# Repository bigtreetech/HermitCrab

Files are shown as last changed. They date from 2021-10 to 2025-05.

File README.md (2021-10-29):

# HermitCrab
* [CanbusKlipper](https://github.com/bigtreetech/HermitCrab/tree/master/CanbusKlipper) contains information about the HermitCrab
 Canbus version
 
 * [Hero Me Gen5 hotend assembly part cooling system](https://www.thingiverse.com/thing:4460970) contains the part cooling system STL files for HermitCrab

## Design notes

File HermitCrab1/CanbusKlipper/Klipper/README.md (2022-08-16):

# How to use Klipper on HermitCrab Canbus version

## Pinout
### HermitCrab Canbus pinout
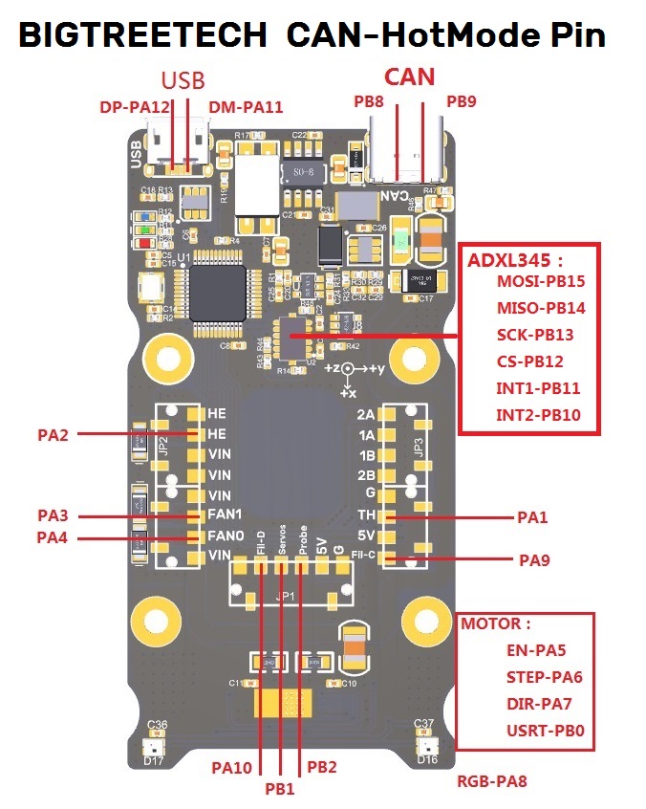
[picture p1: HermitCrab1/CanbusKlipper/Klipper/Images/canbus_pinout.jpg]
<br/>

## Wiring diagram
### Raspberry pi communicates with the hotend board via USB
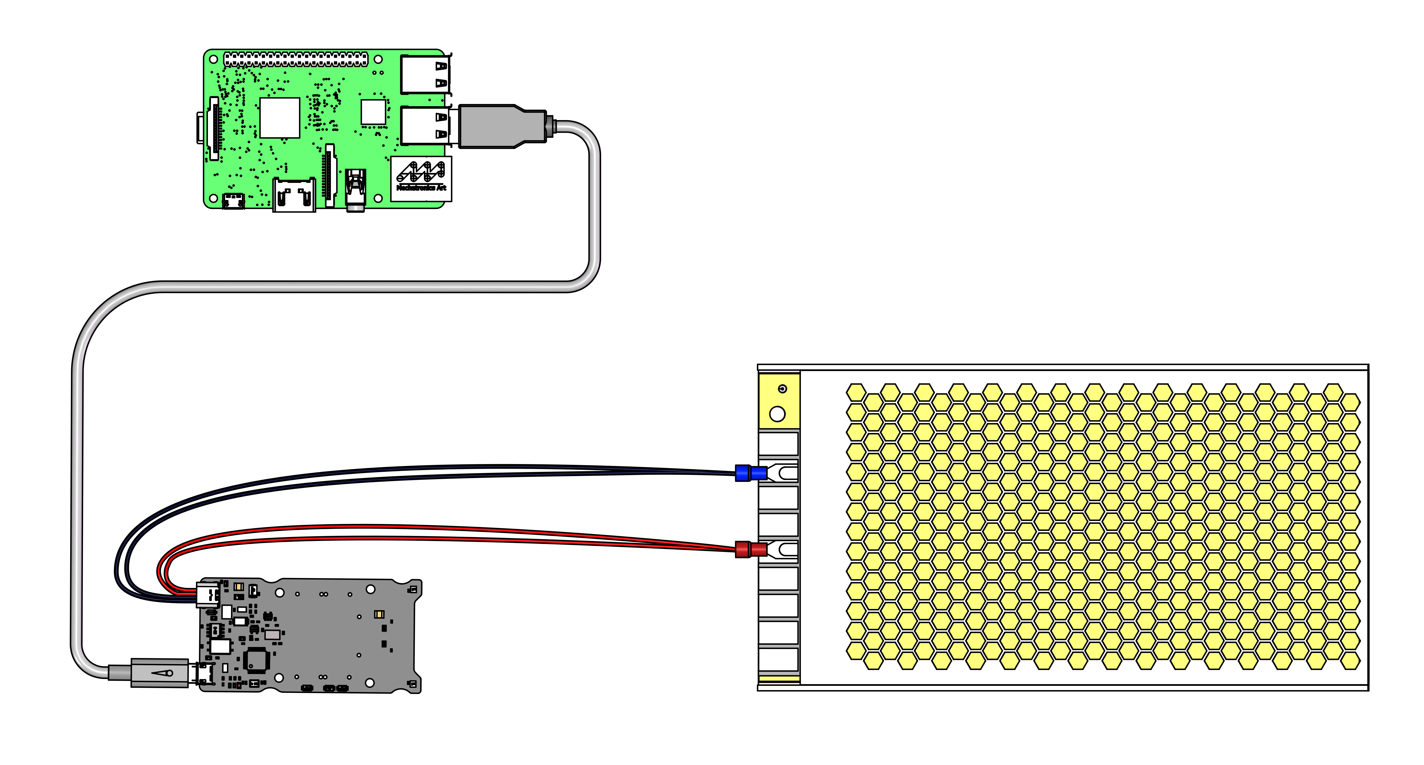
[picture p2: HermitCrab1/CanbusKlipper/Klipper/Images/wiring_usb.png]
<br/>

### Raspberry pi communicates with the hotend board via Canbus
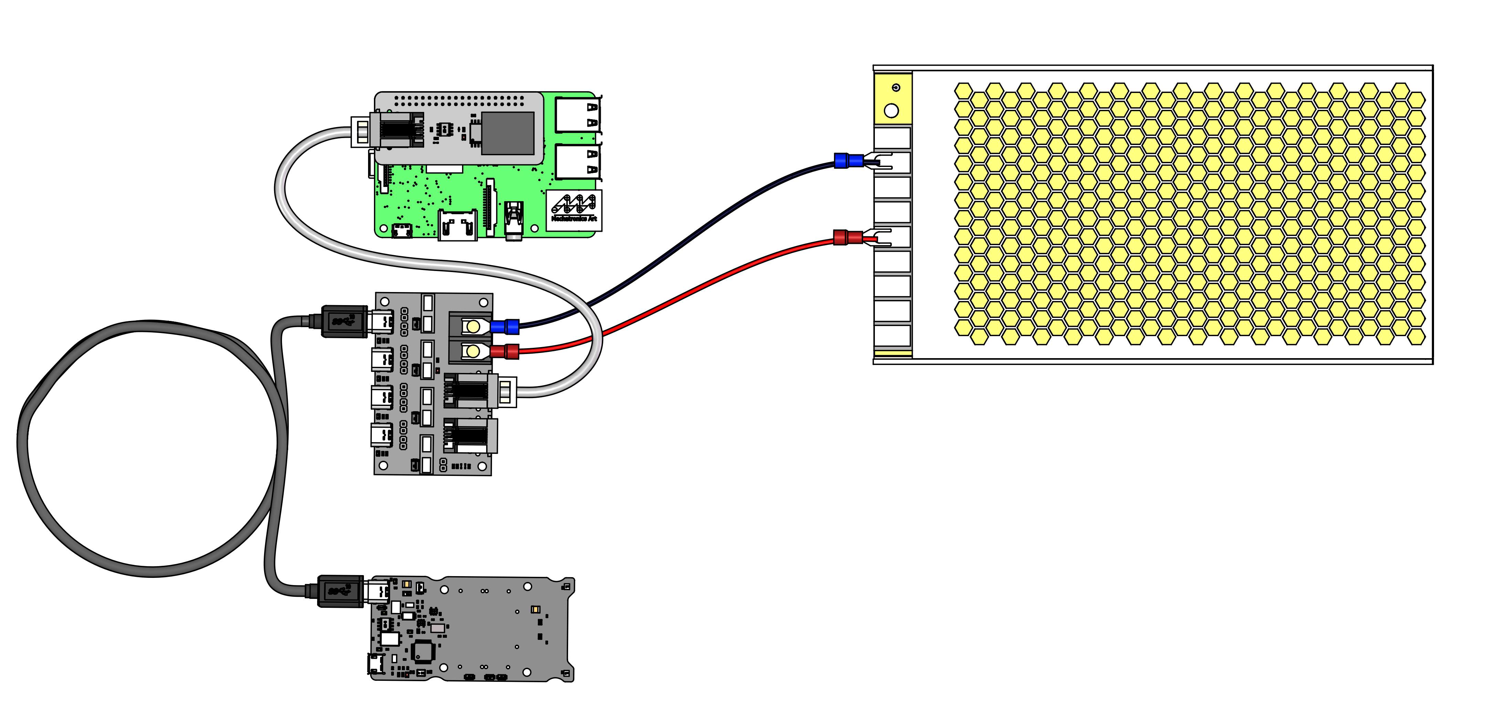
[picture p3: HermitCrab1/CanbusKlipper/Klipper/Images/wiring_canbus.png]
<br/>

## Generate the firmware.bin

1. Precompiled firmware
   * [firmware-F072-USB.bin](./firmware-F072-USB.bin) is the firmware that communicates with raspberry pi through USB
   * [firmware-F072-Canbus.bin](./firmware-F072-Canbus.bin) is the firmware that communicates with raspberry pi through Canbus

2. Build your own firmware
   1. Refer to [klipper's official installation](https://www.klipper3d.org/Installation.html) to download klipper source code to raspberry pi
   2. `Building the micro-controller` with the configuration shown below.
      * [*] Enable extra low-level configuration options
      * Micro-controller Architecture = `STMicroelectronics STM32`
      * Processor model = `STM32F072`(Note: You can set `Processor model` to `STM32F070` or wait for [PR](https://github.com/Klipper3d/klipper/pull/4799) to merge into the master branch and use the latest version of klipper firmware if your firmware has no USB option for `STM32F072`)
      * Clock Reference = `8 MHz crystal)`
      * Bootloader offset = `No bootloader`
      * IF USE USB
         * Communication interface = `USB (on PA11/PA12)`
         * USB ids `0x1d50` for USB vender ID, and `0x614f` for USB device ID. (Note: it is important that hte USB device ID is not the default `0x614e` assigned by Klipper as this causes the device to lose connection during `FIRMWARE_RESTART`
      * ElSE IF USE CANBUS
         * Communication interface = `CAN bus (on PB8/PB9)`
         * CAN bus speed = 250000 ([firmware-F072-Canbus.bin](./firmware-F072-Canbus.bin) default speed is 250K, You can set it by yourself, But you need to reduce the speed if the communication fails)

      <br/>
    3. The `klipper.bin` file will be generated in the folder `home/pi/kliiper/out` after `make`. And you can use the windows computer under the same LAN as raspberry pi to copy `klipper.bin` from raspberry pi to the computer with `pscp` command in the CMD terminal. such as `pscp -C pi@192.168.0.101:/home/pi/klipper/out/klipper.bin c:\klipper.bin`(The terminal may prompt that `The server's host key is not cached` and ask `Store key in cache?((y/n)`, Please type `y` to store. And then it will ask for a password, please type the default password `raspberry` for raspberry pi)

## Update the firmware.bin
1. Connect the USB of the board to your Computer or Raspberry PI through microUSB port(Note: The USB of the board cannot supply power to the MCU, so an external 12/24V is required to supply power to the board).
2. Press and hold the `Boot` button on the back, then click the `Reset` button, and then release the `boot` button. And The MCU has entered DFU mode now.
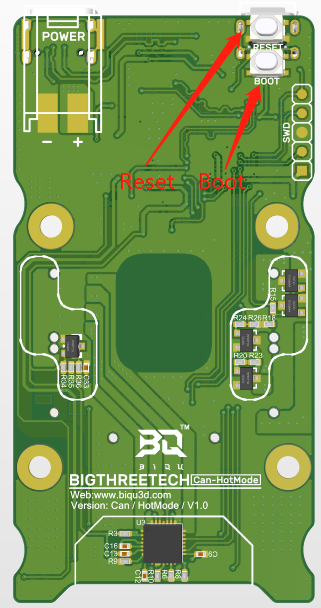
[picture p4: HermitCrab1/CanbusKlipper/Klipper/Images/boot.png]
   <br/><br/>
3. Update the firmware through Computer
   * Download `firmware.bin` into MCU with `STM32CubeProgrammer`, and then click `Reset` button to enter normal working mode.
4. Update the firmware Directly through Raspberry PI
   * from your ssh session, run `lsusb`. and find the ID of the dfu device.
   * run `make flash FLASH_DEVICE=1234:5678` replace 1234:5678 with the ID from the previous step
   * click `Reset` button to enter normal working mode
## Configure the printer parameters
1. [HermitCrab_Canbus_pins.cfg](./HermitCrab_Canbus_pins.cfg) is the configuration file of klipper which contains all pinouts of Canbus hotend board
2. If you use USB to communicate with raspberry pi, run the `ls /dev/serial/by-id/*` command in raspberry pi to get the correct ID number of the motherboard, and set the correct ID number in `printer.cfg`. And wiring reference [here](#raspberry-pi-communicates-with-the-hotend-board-via-usb)
    ```
    [mcu HermitCrab]
    serial: /dev/serial/by-id/usb-Klipper_stm32f072xx_1234
    ```
3. If you use Canbus to communicate with raspberry pi, you need to modify the following files by SSH command. And wiring reference [here](#raspberry-pi-communicates-with-the-hotend-board-via-canbus)<br/>
   Refer to [klipper's official Canbus config](https://www.klipper3d.org/CANBUS.html) to set Canbus
   * Input `sudo nano /boot/config.txt` command, input the password (default: raspberry), Then add the following content to the `config.txt` file
     ```
     dtparam=spi=on
     dtoverlay=mcp2515-can0,oscillator=12000000,interrupt=25,spimaxfrequency=1000000
     ```
     Save(`Ctrl + S`) and Exit(`Ctrl + X`) after modification, input `sudo reboot` to restart raspberry pi
   * Input the `dmesg | grep -i '\(can\|spi\)'` command to test whether MCP2515 has been connected normally after the restart is completed.<br/>
     The normal response should be as follows
     ```
     [ 8.680446] CAN device driver interface
     [ 8.697558] mcp251x spi0.0 can0: MCP2515 successfully initialized.
     [ 9.482332] IPv6: ADDRCONF(NETDEV_CHANGE): can0: link becomes ready
     ```
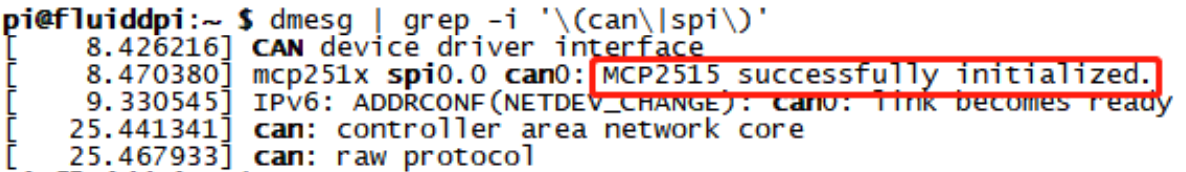
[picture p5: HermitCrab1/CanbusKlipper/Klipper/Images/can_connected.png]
     <br/>
   * Input `sudo nano /etc/network/interfaces.d/can0` command to create a new file named `can0`, and write the following content
     ```
     auto can0
     iface can0 can static
         bitrate 250000
         up ifconfig $IFACE txqueuelen 1024
     ```
     Set the Canbus speed to 250K (consistent with the speed set in [firmware-F072-Canbus.bin](./firmware-F072-Canbus.bin)), and set the `txqueuelen` to 1024 bytes. Save(`Ctrl + S`) and Exit(`Ctrl + X`) after modification, input `sudo reboot`to restart raspberry pi

   * Each micro-controller on the CAN bus is assigned a unique id based on the factory chip identifier encoded into each micro-controller. To find each micro-controller device id, make sure the hardware is powered and wired correctly, and then run:<br/>
     `~/klippy-env/bin/python ~/klipper/scripts/canbus_query.py can0`<br/>
     If uninitialized CAN devices are detected the above command will report lines like the following:<br/>
     `Found canbus_uuid=0e0d81e4210c`<br/>
     set the correct ID number in `printer.cfg`<br/>
     ```
     [mcu HermitCrab]
     canbus_uuid: 0e0d81e4210c
     ```

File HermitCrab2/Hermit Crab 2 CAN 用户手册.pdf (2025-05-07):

# Hermit Crab 2 系列

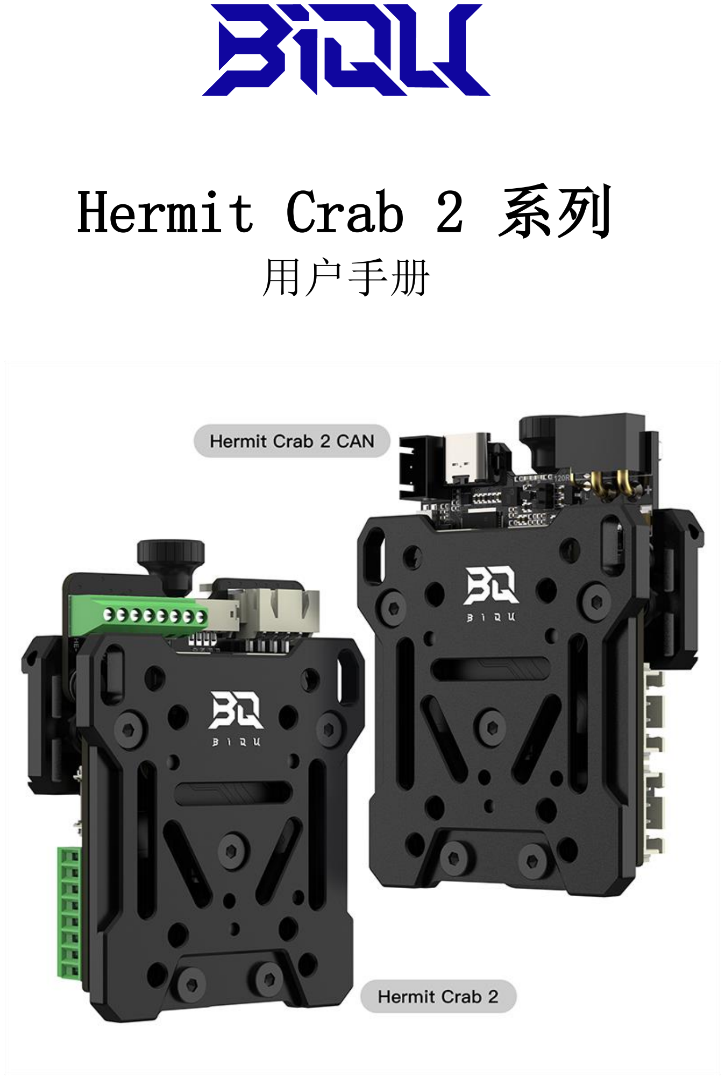
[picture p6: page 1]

# 用户手册

BIQU Hermit Crab 2 系列用户手册

2

目录

3

## 修订历史

版本 | 日期 | 修订历史
v1.00 | 2023/06/14 | 初稿
v1.01 | 2025/05/07 | menuconfig 配置修改为 Flash chip
(GENERIC_03H with CLKDIV 4)

4

## 一、产品简介

Hermit Crab 2 系列专为快速更换工具头而设计。该系列配备了一个固定板和多个工具板， 使用户能够根据不同需求迅速切换不同的打印头。2 系列更为轻便、更为紧凑，同时具备 更强的稳固性。

### 1.1 产品特点

- 主板预留 BOOT 按键，用户可以通过 USB 进入 DFU 模式更新固件
- 热敏电阻部分增设保护电路，避免因加热棒漏电导致主控芯片烧毁
- 预留 I

2
C、RGB 等接口，可供客户 DIY 多种功能使用
- 数控风扇电压可选，增强对风扇类型的兼容性
- USB 通电通过跳线帽选择，有效隔离主板 DC-DC 与 USB5V
- 接近开关，2 线风扇，4 线风扇支持 VIN/12V/5V 电压选择
- 加热棒及风扇端口增加防反激二极管及保险丝，有效保护 MOS 管不被反向电压烧毁
- 艾迈斯电源接口，支持更大的电流输入，且增加防反接保护电路，避免出现客户接反 电源线烧板的现象
- 支持 2 线 PT100/PT1000/NTC100K 选择
- 支持 CAN 或 USB 通讯，其中 CAN 的终端电阻 120R 可通过跳线帽选择，且预留 CAN 拓展 接口
- USB 口设 ESD 保护芯片，防止主控被 USB 口静电击穿
- 5V 和 12V 增加 E-FUSE 保护芯片，大大降低因短路或者打火等故障导致芯片被烧毁的 风险
- 增设精度更高的 LIS2DW 加速度计，方便客户更好的使用共振补偿功能

5

### 1.2 产品参数

| Hermit Crab 2 | Hermit Crab 2 CAN
固件支持 | Klipper, Marlin, RRF | Klipper
板载加速度计 | - | LIS2DW
板载 Max31865 | - | √
CAN 接口 | - | XT30
微处理器 | - | RP2040 Dual ARM Cortex-M0+@133MHz
材质 | 铝合金 | 铝合金
输入电压 | DC12V-24V | DC12V-24V
逻辑电压 | - | DC 3.3V
加热接口 | 加热棒（HE0），最大输出电 流：3A | 加热棒（HE0），最大输出电 流：6A
风扇接口 | 2x 2 线数控风扇（FAN1，FAN2）， 1x4 线风扇（FAN0），支持电压可 选 | 2x 2 线数控风扇（FAN1，FAN2）， 1x4 线风扇（FAN0），支持电压可 选
风扇接口最大输 出电流 | 0.75A，峰值 0.9A | 0.75A，峰值 0.9A
拓展接口 | RGB, I2C, Probe | I2C，Probe，RGB，USB，CAN， STOP
电机驱动 | - | TMC2209
驱动工作模式 | - | UART
步进电机接口 | E0 | E0
温度传感器接口 | - | 1 路 NTC100K/PT100/PT1000 可选
USB 通信接口 | - | USB Type-C
DCDC 5V 输出最 大电流 | 1A | 1A

### 1.3 产品尺寸

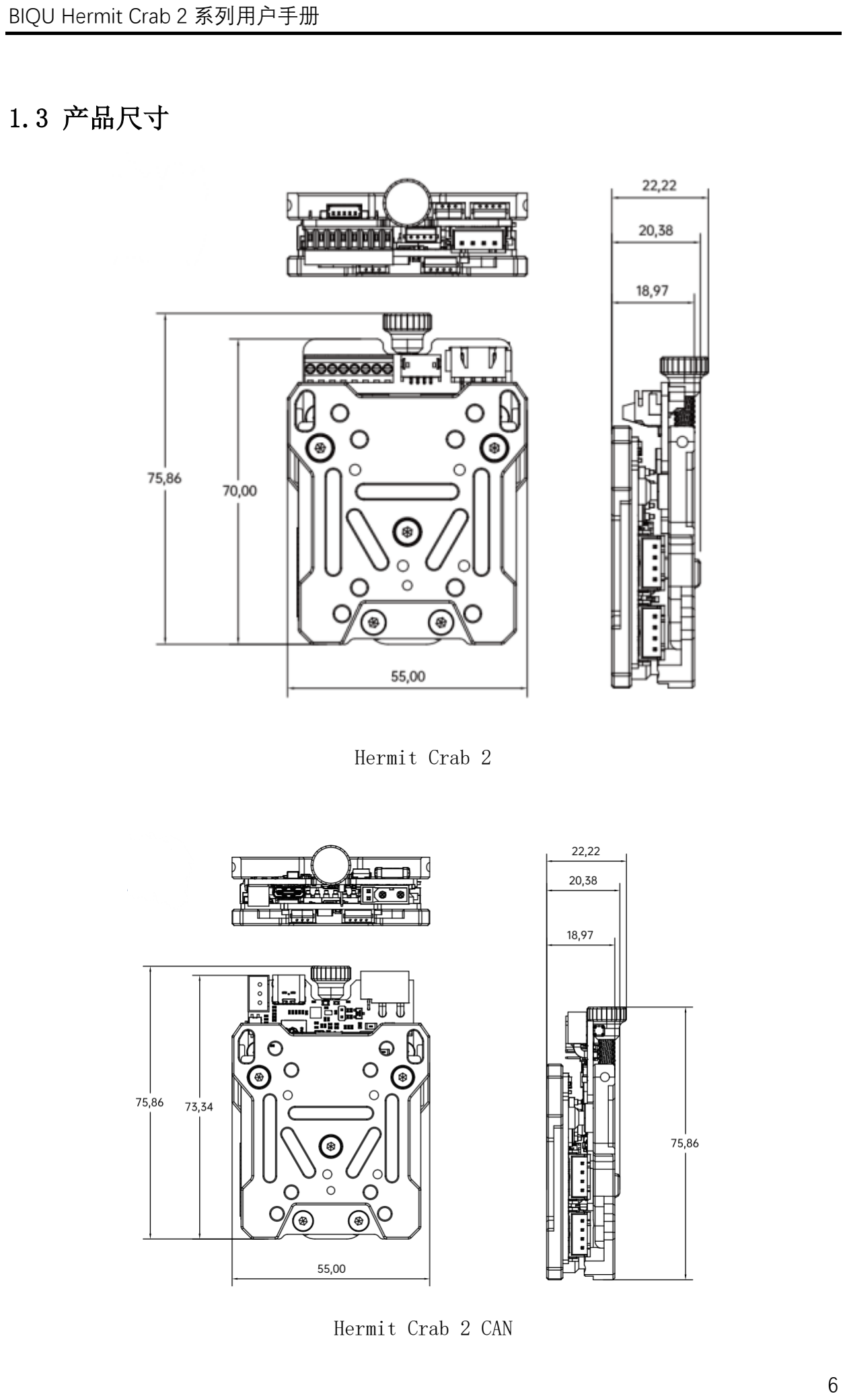
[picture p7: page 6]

6

Hermit Crab 2

Hermit Crab 2 CAN

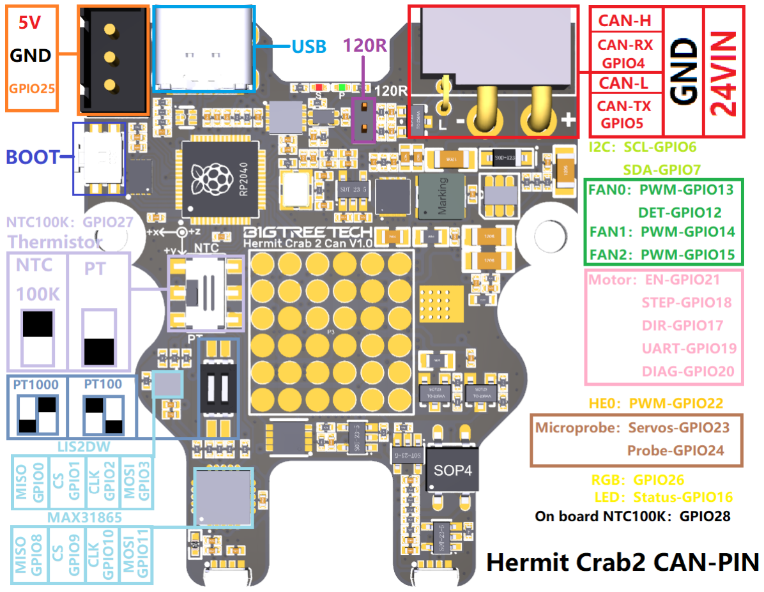
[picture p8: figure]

7

## 二、外设接口

### 2.1 Pin 脚说明

Hermit Crab 2 CAN-PIN

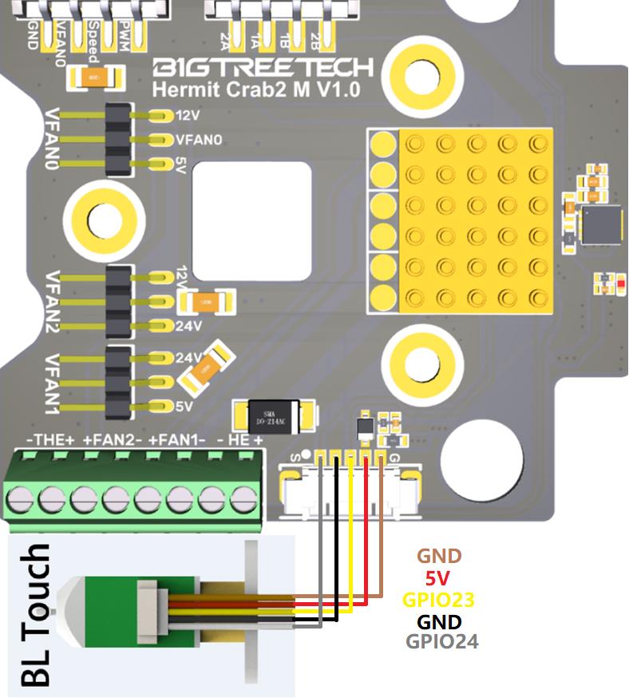
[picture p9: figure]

8

## 三、接线

### 3.1 BLTouch 接线

### 3.2 风扇电压选择

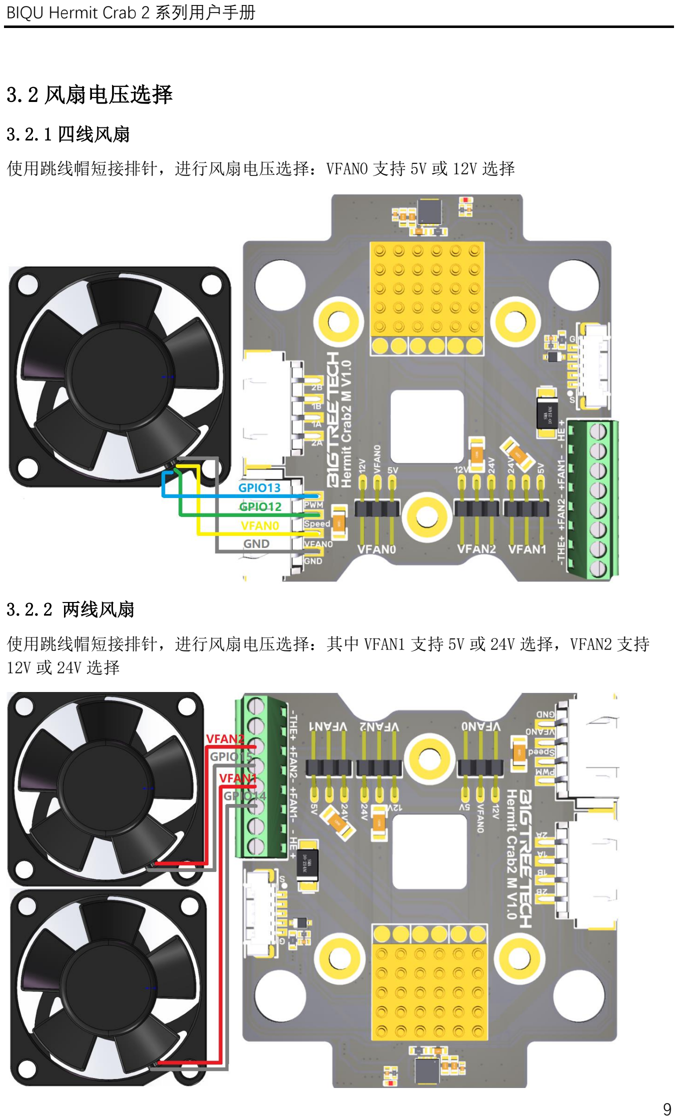
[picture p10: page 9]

9

3.2.1 四线风扇

使用跳线帽短接排针，进行风扇电压选择：VFAN0 支持 5V 或 12V 选择

3.2.2 两线风扇

使用跳线帽短接排针，进行风扇电压选择：其中 VFAN1 支持 5V 或 24V 选择，VFAN2 支持 12V 或 24V 选择

10

### 3.3 RGB 接线

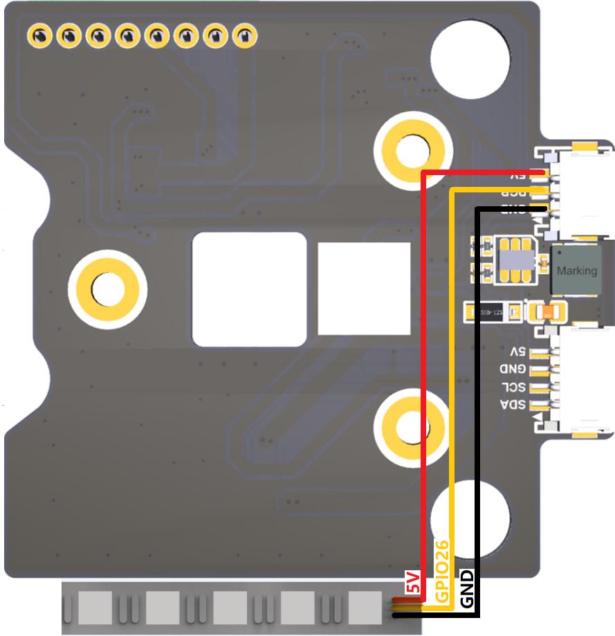
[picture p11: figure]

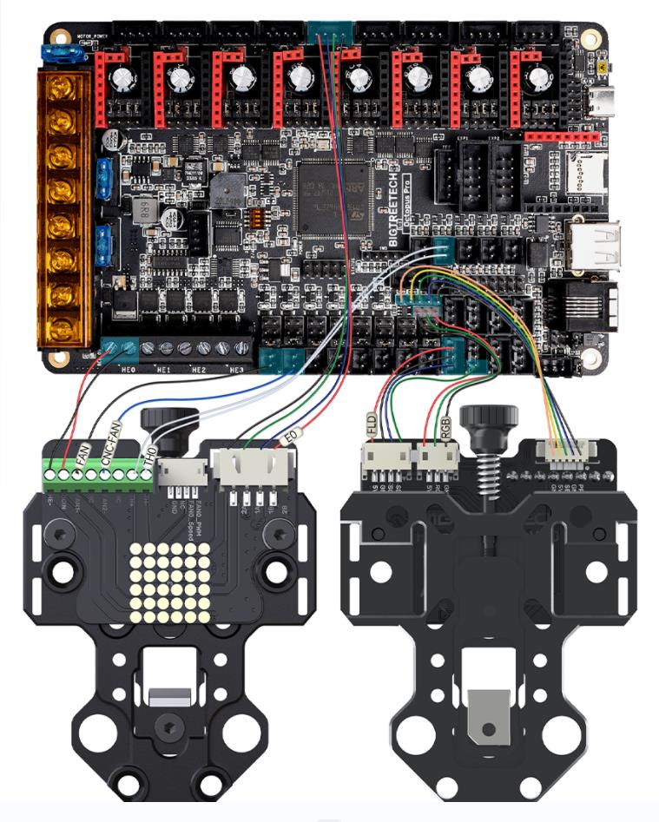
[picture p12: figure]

11

### 3.4 Octopus Pro 与 Hermit Crab 2 接线

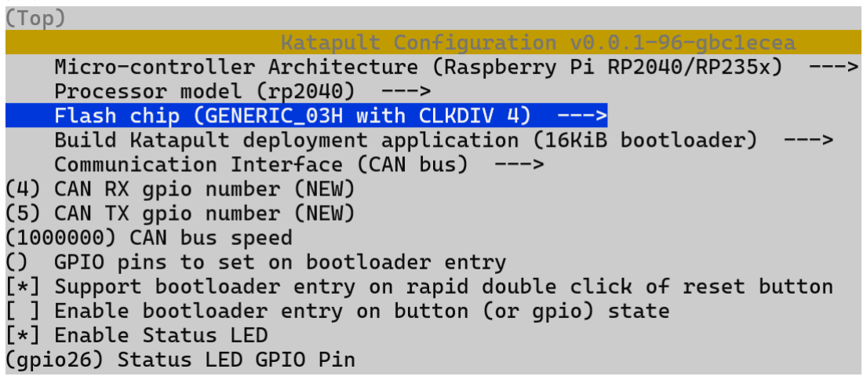
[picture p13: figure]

12

## 四、固件设置

### 4.1 烧录 KATAPULT

注意：Katapult 旨在通过 CAN bus 接口直接更新 MCU 固件，若您更倾向于使用 DFU 更新方法，请跳过此步骤。

“树莓派或 CB1 烧录 Katapult”，参考此处说明下载 Katapult 工程 https://github.com/Arksine/Katapult

(1) 输入
cd ~
跳转到主目录，输入
git clone https://github.com/Arksine/Katapult 下载 Katapult 工程，然后输入
cd Katapult
跳转到 Katapult 目录中。
(2) 输入
make menuconfig
并按照下图配置
(3) 输入 make 编译固件，当 make 执行完成后会在 home/biqu/Katapult/out 文件夹 中生成我们所需要的‘katapult.uf2’固件，在 SSH 软件左侧可以直接下载到电

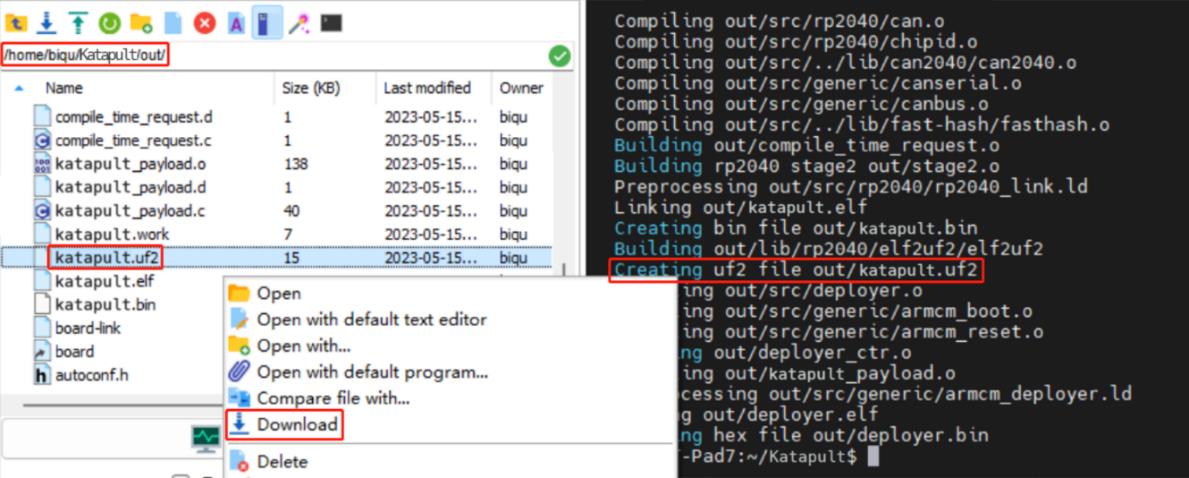
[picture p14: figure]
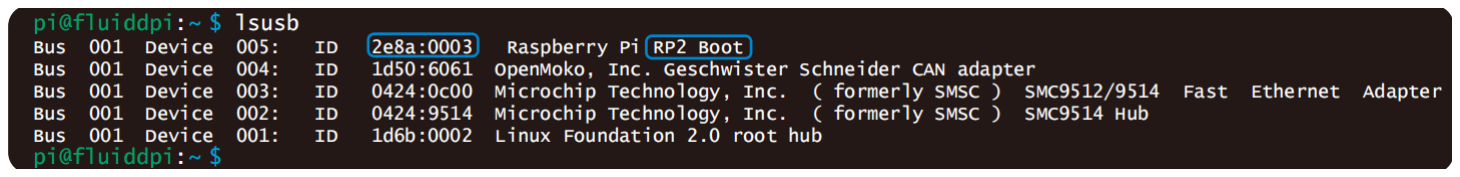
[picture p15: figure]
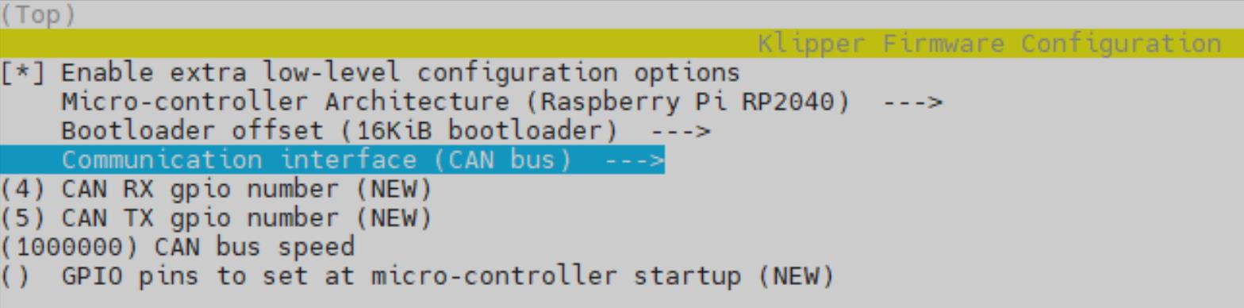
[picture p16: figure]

13

脑中；

(4) 请按住 Boot 按钮，然后使用 Type-C 线连接至树莓派/CB1，此时芯片进入 DFU 模 式
(5) 在 SSH 终端命令行中输入
lsusb
查询 DFU 设备 ID
(6) 请输入以下命令以烧录 Katapult
make flash FLASH_DEVICE=2e8a:0003 其中“2e8a:0003”需替换为上一步中查询到的实际设备 ID
(7) 烧录完成后，请拔下 Type-C 数据线。

### 4.2 编译 Klipper 固件

(1) SSH 连接到 CB1/树莓派后，在命令行输入：
cd ~/klipper/
make menuconfig
使用下面的配置编译固件(如果没有下列选项，请更新 Klipper 固件源码到最新版 本)；

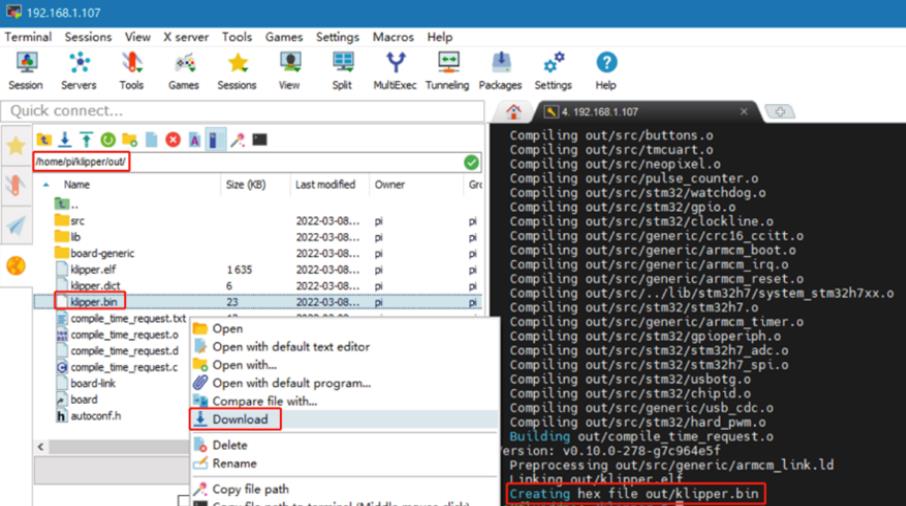
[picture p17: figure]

14

[*] Enable extra low-level configuration options
Micro-controller Architecture (Raspberry Pi RP2040/RP235x) ---> Processor model (rp2040) --->
如果不使用 Katapult
Bootloader offset (No bootloader) --->
Flash chip (GENERIC_03H with CLKDIV 4) ---> 如果使用 Katapult
Bootloader offset (16KiB bootloader) ---> 如果使用 Type-C 上的 USB 通信
Communication Interface (USBSERIAL) ---> 如果使用 CANBus 通信
Communication interface (CAN bus) --->
(4) CAN RX gpio number
(5) CAN TX gpio number
(1000000) CAN bus speed
(2) 配置选择完成后, 输入 ‘q’退出配置界面，当询问是否保存配置时选择 “Yes”；
(3) 输入 make 编译固件，当 make 执行完成后会在 home/pi/klipper/out 文件夹中生 成我们所需要的‘klipper.bin’固件，在 SSH 软件左侧可以直接下载到电脑中

### 4.3 通过 KATAPULT 进行固件更新

(1) 使用 CAN bus 需要接好 CAN bus 线缆以及插上 120R 终端电阻的跳线帽。
(2) 输入
cd ~/Katapult/scripts
然后输入

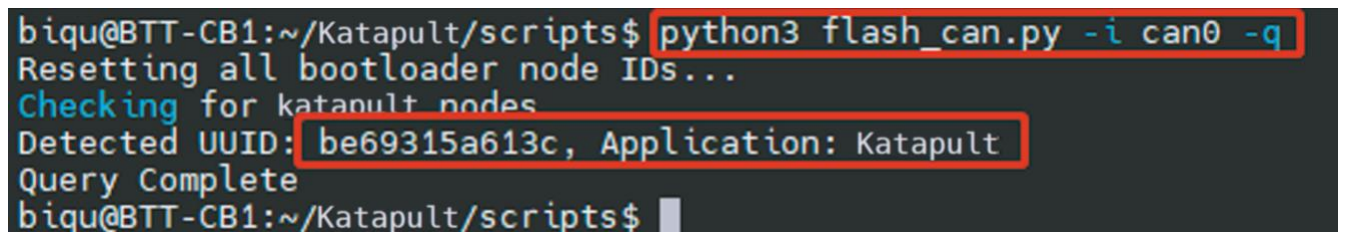
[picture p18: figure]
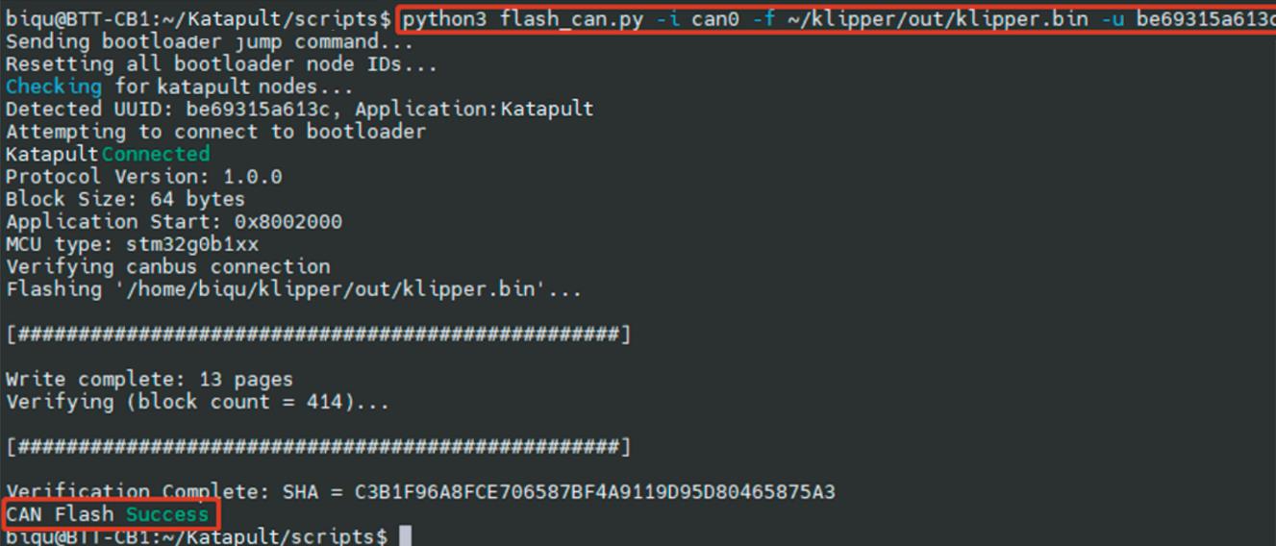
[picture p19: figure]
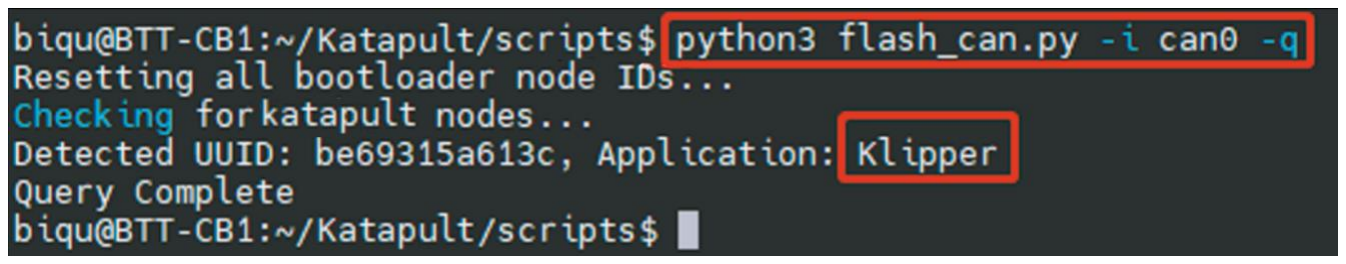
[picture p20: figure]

15

python3 flash_can.py -i can0 -q
查询 canbus ID （需提前接好 CAN 线并通电），如下图已找到设备的 UUID
(3) 输入
python3 flash_can.py -i can0 -f ~/klipper/out/klipper.bin -u be69315a613c
替换为实际的 UUID，注意：klipper.bin 需要提前 make 生成出来，并且 Katapult 的 Application start offset 为 16KiB offset，所以 Klipper 的 menuconfig 中 Bootloader offset 也要为 16KiB bootloader，如下图已经烧录 成功。
(4) 再次输入
python3 flash_can.py -i can0 -q
查询，此时 Application 由之前的 Katapult 变为 Klipper，代表 Klipper 已经正 常运行

### 4.4 通过 DFU 进行固件更新

树莓派或 CB1 通过 DFU 更新

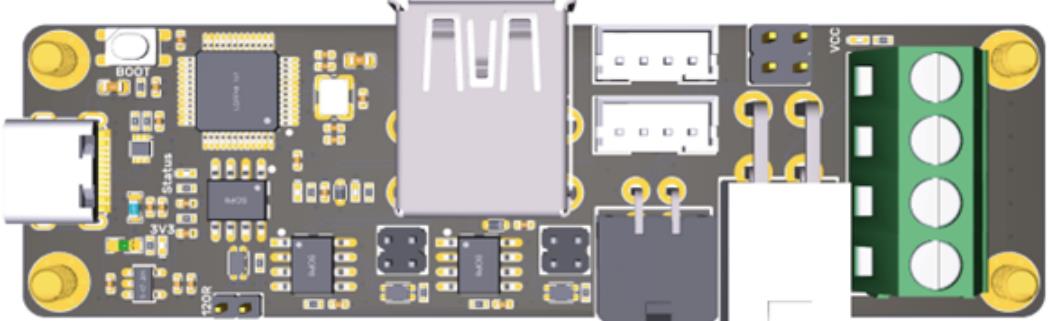
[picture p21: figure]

16

(1) 请按住 Boot 按钮，然后使用 Type-C 线连接至树莓派/CB1，此时芯片进入 DFU 模 式
(2) 在 SSH 终端命令行中输入
lsusb
查询 DFU 设备 ID
(3) 输入
cd klipper
跳转到 klipper 目录下，输入
make flash FLASH_DEVICE=2e8a:0003
开始烧录固件（注意：将 2e8a:0003 更换为上一步中查询到的实际的设备 ID）
(4) 固件烧录完成后，输入
ls /dev/serial/by-id/
查询设备的 Serial ID（只有通过 USB 通信的方式才会有此 ID，CANBus 方式忽略 此步骤)。
(5) 如果使用 USB 通信，第一次烧录完成之后，再次更新时无需手动按 Boot
按钮进入 DFU 模式，可以直接输入
make flash FLASH_DEVICE=/dev/serial/by-id/usb-Klipper_rp2040_4550357128922FC8-if00
烧录固件（注意：将/dev/serial/by-id/xxx 更换为上一步中查询到的实际的 ID）。
(6) 如果使用 CAN bus 通信，烧录完成后，请拔下 Type-C 数据线。

### 4.5 CAN bus 配置

搭配 BIGTREETECH U2C 模块使用

(1) 在 SSH 终端中输入
sudo nano /etc/network/interfaces.d/can0 命令,新增以下内容
allow-hotplug can0

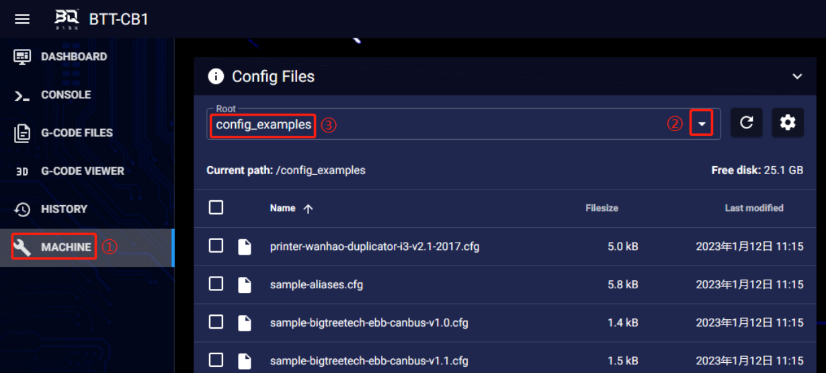
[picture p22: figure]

17

iface can0 can static
bitrate 1000000
up ifconfig $IFACE txqueuelen 1024
将 CAN bus 速度设置为 1M（必须与固件中设置的速度一致(1000000) CAN bus speed），修改后保存（Ctrl + S）并退出（Ctrl + X），输入
sudo reboot
重启树莓派。
(2) CANBus 上的每个设备都会根据 MCU 的 UID 生成一个 canbus_uuid，要查找每个微 控制器设备 ID，请确保硬件已通电并正确接线，然后运行： ~/klippy-env/bin/python ~/klipper/scripts/canbus_query.py can0
(3) 如果检测到未初始化的 CAN 设备，上述命令将报告设备的 canbus_uuid
Found canbus_uuid=0e0d81e4210c
(4) 如果 Klipper 已经正常运行并且连接到此设备，那么 canbus_uuid 将不会被上报， 此为正常现象。

### 4.6 配置 Klipper

(1) 在电脑的浏览器中输入树莓派的 IP 访问，如下图所示的路径中下载名为 “sample-bigtreetech-hermit-crab-2-canbus.cfg”的参考配置，如果找不到此 文件，请更新 Klipepr 固件源码到最新版本，或者到 GitHub 下载： https://github.com/bigtreetech/HermitCrab

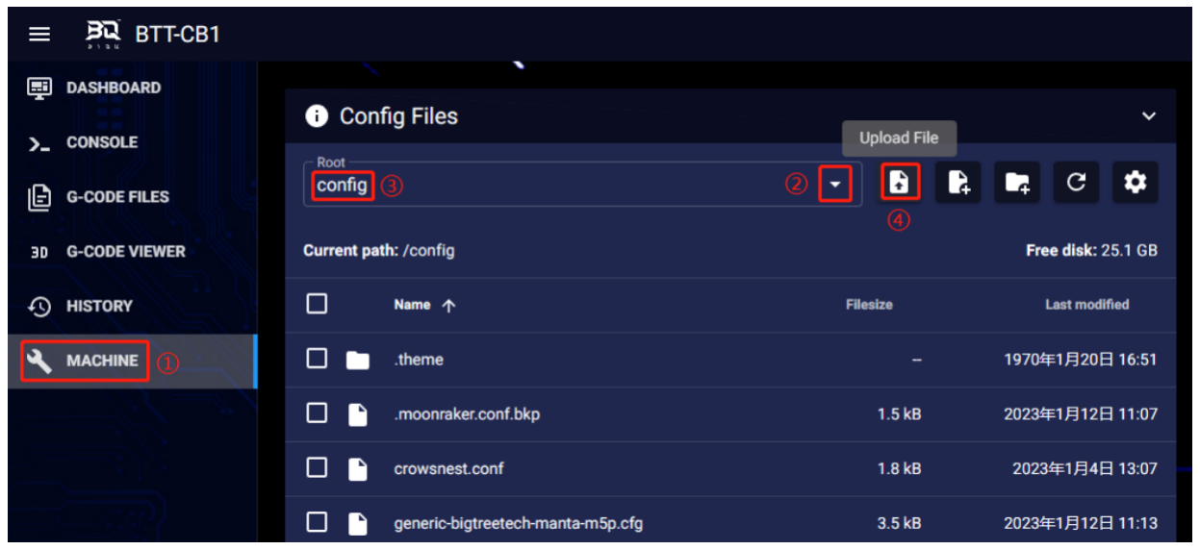
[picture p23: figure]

18

(2) 将主板的配置文件上传到 Configuration Files 中;
(3) 并在“printer.cfg”文件中添加此主板的配置
[include sample-bigtreetech-hermit-crab-2-canbus.cfg]
(4) 将配置文件中的 ID 号修改为主板实际的 ID（USB serial 或者 canbus）
(5) 按照下方链接的说明配置模块的具体功能：
https://www.klipper3d.org/Overview.html

## 五、注意事项

1. 使用 CAN 通讯时，需要看是否用作终端，如果是终端，必须将 120R 位置插上跳线帽；
2. 接线时需注意线序，对照 Pin 图进行 DIY，避免电源线接反或者接到 CAN 信号中去，导 致模块烧毁；
3. 通过 USB 端口烧录程序时，如果未外接电源，需将 VUSB 使用跳线帽短接，以便给模块 提供工作电压；
4. 加热棒及风扇接口负载电流不得大于最大承受电流，以防烧坏 MOS 管。

## 六、FAQ

问：加热棒、风扇端口的最大电流
答：加热棒端口最大输出电流：6 A
风扇接口最大输出电流：1A，峰值 1.5A
加热棒+驱动+风扇的总电流需小于 9A。

问：USB 接口无法更新固件
答：确保 VUSB 跳线帽有插入，主板上的电源指示灯正常亮起。

19

如果您还需要此产品的其他资源，可以到 https://github.com/bigtreetech/ 上自行查找， 如果无法找到您所需的资源，可以联系我们的售后支持（service005@biqu3d.com）。

若您使用中还遇到别的问题，欢迎您联系我们，我们定会细心为您解答；若您对我们的产 品有什么好的意见或建议，也欢迎您回馈给我们，我们也会仔细斟酌您的意见或建议，感 谢您选择 BIGTREETECH 制品，谢谢！

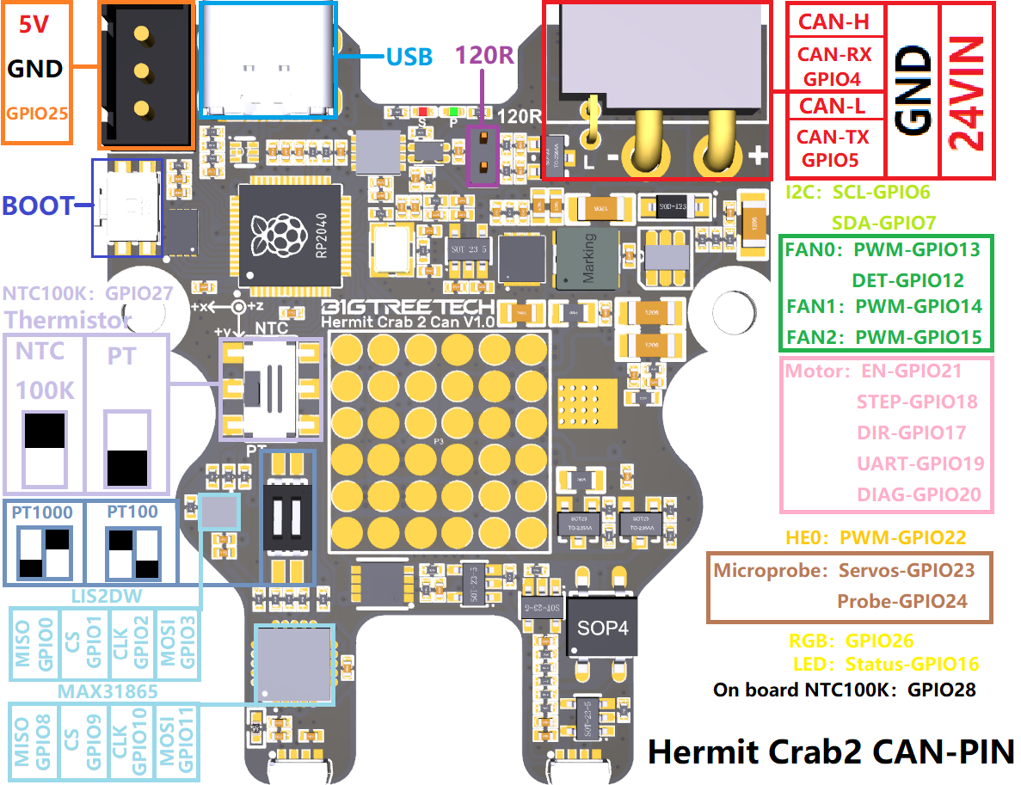
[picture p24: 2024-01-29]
HermitCrab2/Hardware/Hermit Crab 2-PIN.png

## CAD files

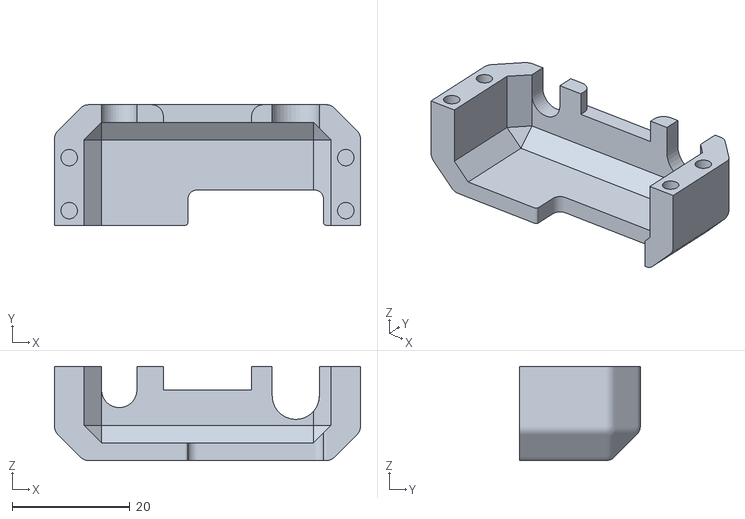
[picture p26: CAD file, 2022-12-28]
HermitCrab1/STL/hermit crab standard cable cover.STL
52.0 x 20.5 x 16.0

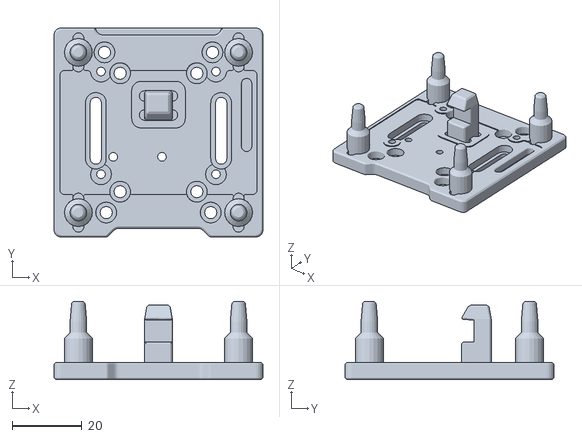
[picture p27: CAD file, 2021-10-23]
HermitCrab1/STL/BIQU HERMIT CRAB TOOL PLATE.stl
60.0 x 60.0 x 22.5

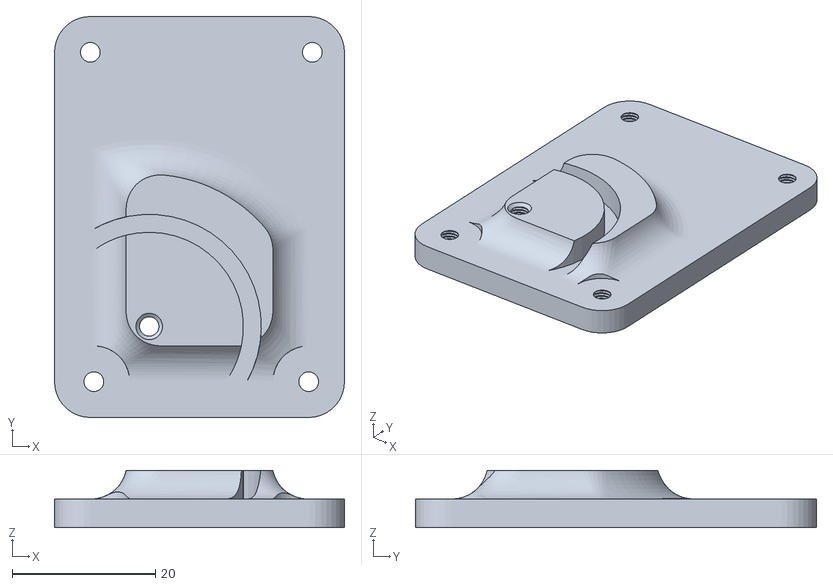
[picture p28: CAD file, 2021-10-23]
HermitCrab1/STL/pen.STL
40.5 x 56.0 x 8.00

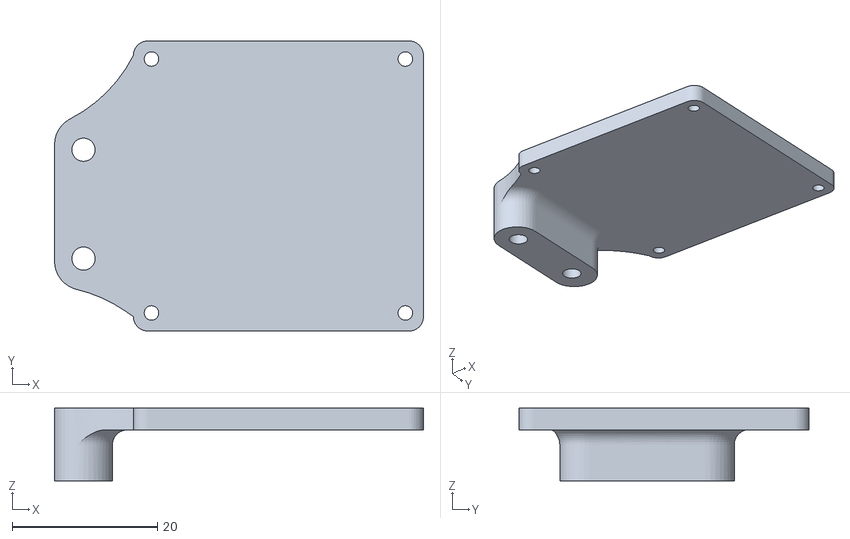
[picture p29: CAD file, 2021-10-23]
HermitCrab1/STL/bracket.STL
50.9 x 40.0 x 10.0

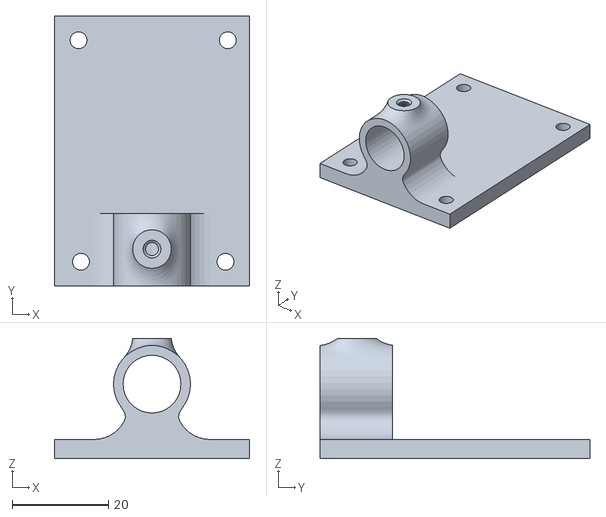
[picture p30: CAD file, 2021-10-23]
HermitCrab1/STL/plotter.STL
40.5 x 56.0 x 25.0

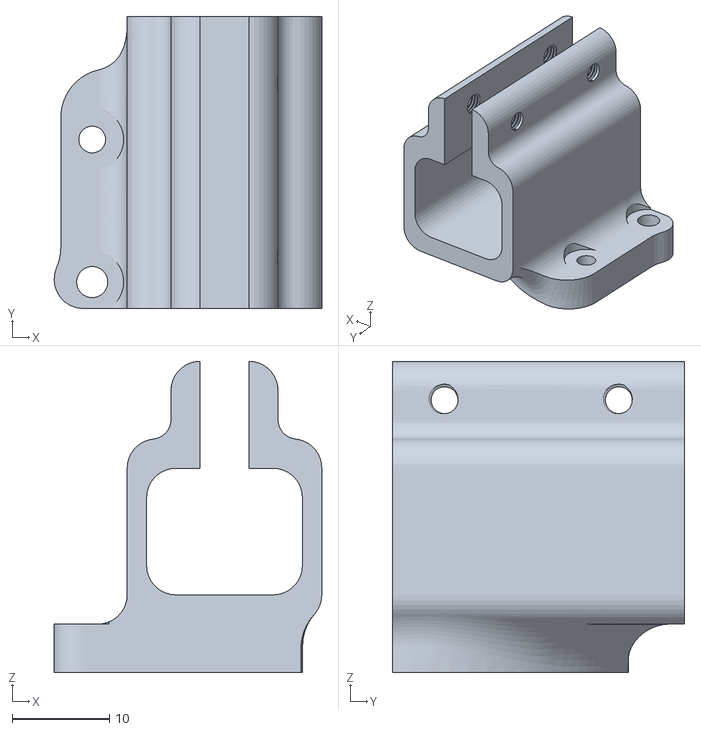
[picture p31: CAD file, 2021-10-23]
HermitCrab1/STL/penclamp.STL
27.5 x 30.0 x 32.0

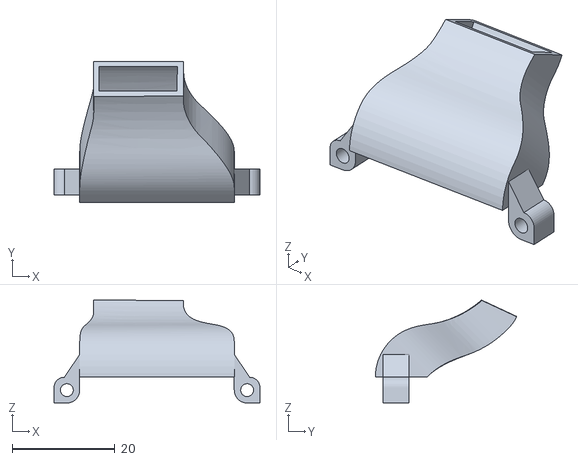
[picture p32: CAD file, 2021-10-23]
HermitCrab1/STL/nozzle.STL
40.0 x 27.5 x 20.0

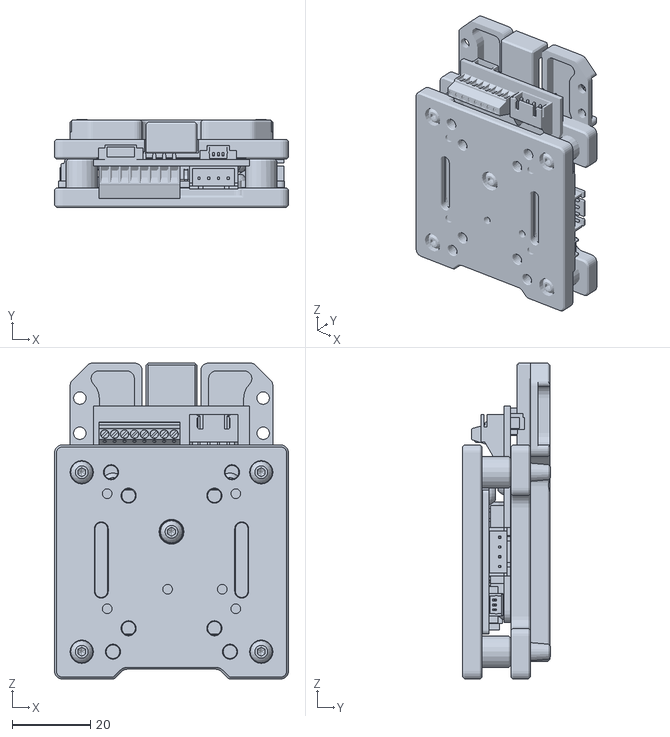
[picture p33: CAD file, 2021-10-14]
HermitCrab1/STL/HERMIT CRAB.stl
60.0 x 22.5 x 81.0

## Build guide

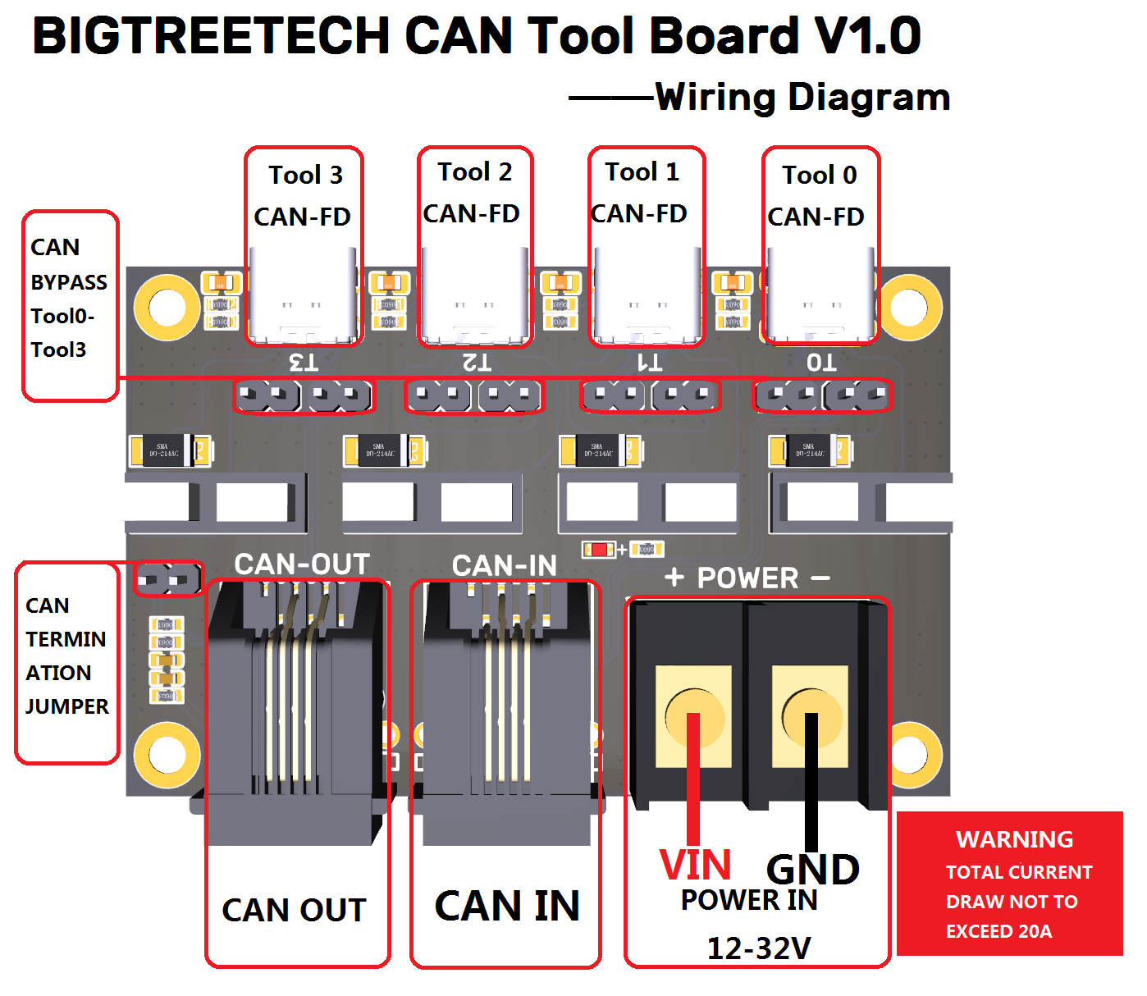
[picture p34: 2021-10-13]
HermitCrab1/CanbusKlipper/Hardware/BTT CAN-Tool Board V1.0/BTT CAN-Tool Board V1.0 Wiring Diagram.png

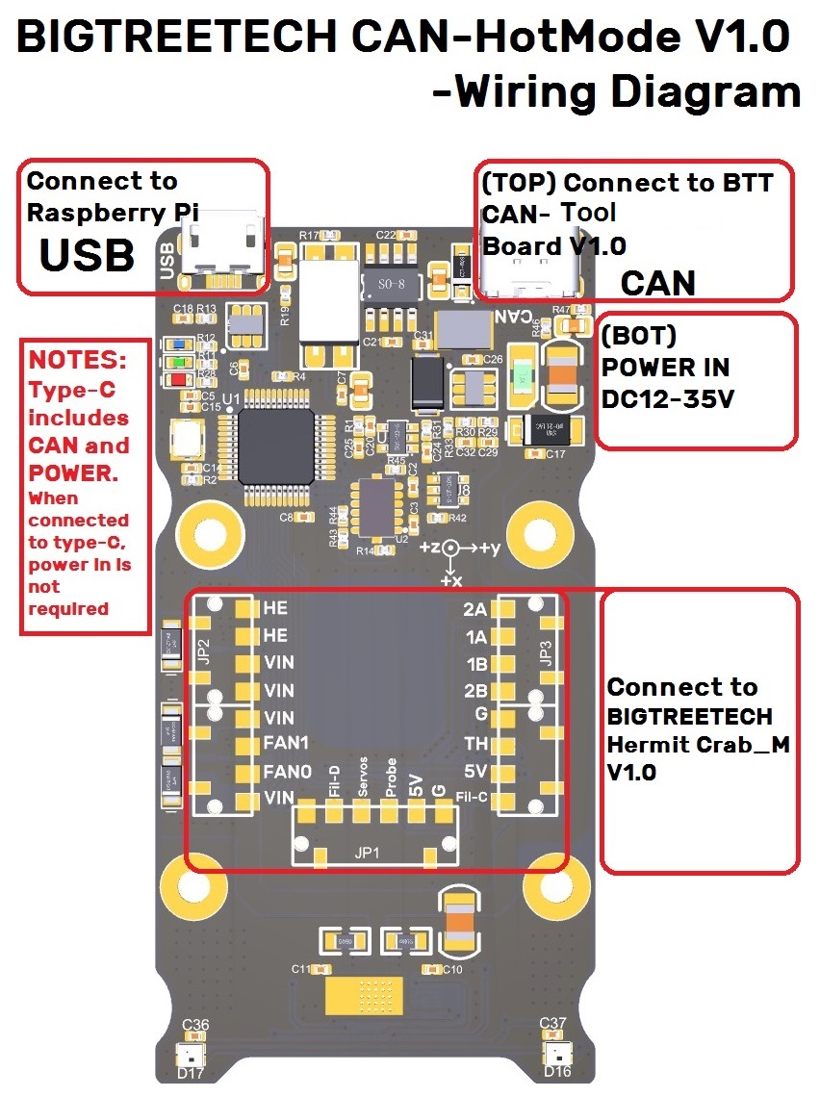
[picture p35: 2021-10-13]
HermitCrab1/CanbusKlipper/Hardware/BTT CAN-HotMode V1.0/BTT CAN-HotMode V1.0-Wiring Diagram.jpg

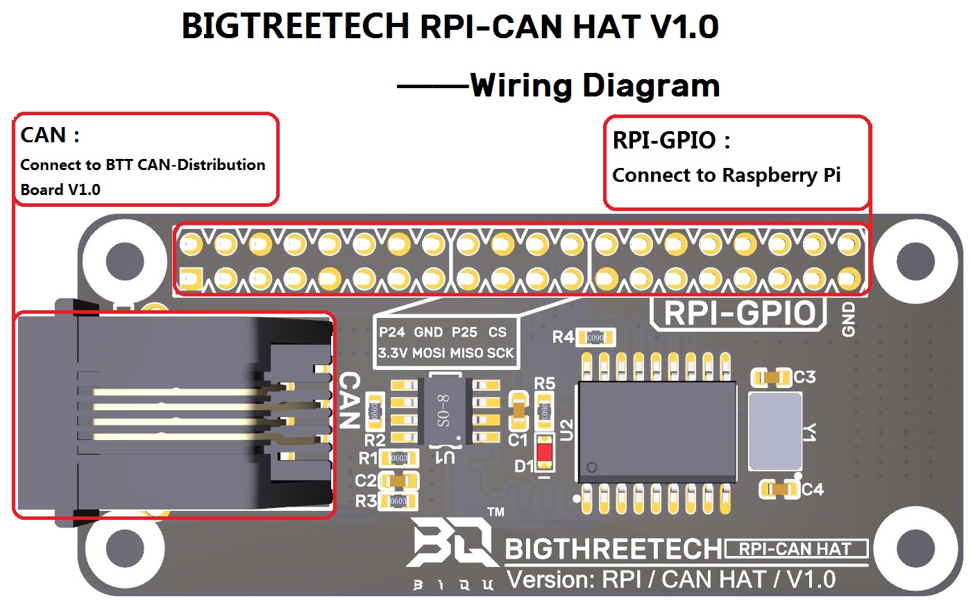
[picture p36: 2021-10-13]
HermitCrab1/CanbusKlipper/Hardware/BTT RPI-CAN HAT V1.0/BTT RPI-CAN HAT V1.0 Wiring Diagram.jpg

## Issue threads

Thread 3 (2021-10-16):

how to fix bltouch ?

grimlokason, 2021-10-16:
Hello

in HermitCrab/CanbusKlipper/Klipper/Canbus_hotend_pins.cfg  you are specifiying the bltouch offset but there is no information on which support to use neither in the config file nor in the pdf.

Is it possible to get it or a link to it ?

Best regards.

thisiskeithb, 2021-11-02:
>  you are specifiying the bltouch offset but there is no information on which support to use neither in the config file nor in the pdf

Insert your own values. Those are just dummy values to get you started since everyone's printer/hotend is different.

grimlokason, 2021-11-21:
ok, thank you !

Closed 2021-11-21.

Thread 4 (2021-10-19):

Ender 3 // CR10 mounting bracker POM wheels not compatible.

ihagens, 2021-10-19:
the timing belds are to short for the standard POM carriage. Mounting holes fot the belds are to close to each other which makes the belds to short.

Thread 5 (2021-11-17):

No Max Power Spec in Documentation

zedn4c3r, 2021-11-17:
None of the documentation lists a max power load for items attached to the tool plate.

zedn4c3r, 2022-02-08:
Part of the intended use case for this product is to be able to connect laser tool heads and other hardware to the tool plate. The selection of a laser is highly dependent on how much power it can provide.

mikerocklewitz, 2022-07-02:
I second this.

I received a hermit crab can for review purposes and i have no idea how much i can push thru it or what my max heater size can be.

The power connector for micro usb mode looks undersized, but the tool board for usb c has 5 amp fuses.....i dont know what this means

What is the max heater cartridge a person can use?

cd85233, 2022-08-12:
Posted elsewhere but I'd also like to know the 5v ratings. Most importantly the maximum current it can source.

HWiese1980, 2022-12-13:
Should definitely be! I almost grilled my Crab due to too high current

eliasmagn, 2023-01-26:
Its a joke they didnt provided any information on that till this day!
I have three hermit crab and i am considering to never buy btt stuff again !

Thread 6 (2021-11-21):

Error : "Endstop and stepper must be on the same mcu"  while using bltouch

grimlokason, 2021-11-21:
Hello,

I'm getting the following error on fluiddpi :
```Endstop and stepper must be on the same mcu```

My config for my ender 3 with the hermit crab canbus on usb :

```
# This file contains pin mappings for the stock 2020 Creality Ender 3
# V2. To use this config, during "make menuconfig" select the
# STM32F103 with a "28KiB bootloader" and serial (on USART1 PA10/PA9)
# communication.

# If you prefer a direct serial connection, in "make menuconfig"
# select "Enable extra low-level configuration options" and select
# serial (on USART3 PB11/PB10), which is broken out on the 10 pin IDC
# cable used for the LCD module as follows:
# 3: Tx, 4: Rx, 9: GND, 10: VCC

# Flash this firmware by copying "out/klipper.bin" to a SD card and
# turning on the printer with the card inserted. The firmware
# filename must end in ".bin" and must not match the last filename
# that was flashed.

# See docs/Config_Reference.md for a description of parameters.

[stepper_x]
step_pin: PC2
dir_pin: PB9
enable_pin: !PC3
microsteps: 16
rotation_distance: 40
endstop_pin: ^PA5
position_endstop: 0
position_max: 235
homing_speed: 50

[stepper_y]
step_pin: PB8
dir_pin: PB7
enable_pin: !PC3
microsteps: 16
rotation_distance: 40
endstop_pin: ^PA6
position_endstop: 0
position_max: 235
homing_speed: 50

[stepper_z]
step_pin: PB6
dir_pin: !PB5
enable_pin: !PC3
microsteps: 16
rotation_distance: 81
endstop_pin: probe:z_virtual_endstop
position_max: 250

[heater_bed]
heater_pin: PA2
sensor_type: EPCOS 100K B57560G104F
sensor_pin: PC4
control: pid
# tuned for stock hardware with 50 degree Celsius target
pid_Kp: 54.027
pid_Ki: 0.770
pid_Kd: 948.182
min_temp: 0
max_temp: 130

[mcu]
serial: /dev/serial/by-id/usb-1a86_USB_Serial-if00-port0
restart_method: command

[printer]
kinematics: cartesian
max_velocity: 300
max_accel: 3000
max_z_velocity: 5
max_z_accel: 100

########################

[mcu HermitCrab]
#canbus_uuid: 0e0d81e4210c
serial: /dev/serial/by-id/usb-Klipper_stm32f072xb_23001D001657434233343820-if00

[adxl345]
cs_pin: HermitCrab: PB12
spi_software_sclk_pin: HermitCrab: PB13
spi_software_mosi_pin: HermitCrab: PB15
spi_software_miso_pin: HermitCrab: PB14
axes_map: y,z,-x
#   The accelerometer axis for each of the printer's x, y, and z axes.
#   This may be useful if the accelerometer is mounted in an
#   orientation that does not match the printer orientation. For
#   example, one could set this to "y,x,z" to swap the x and y axes.
#   It is also possible to negate an axis if the accelerometer
#   direction is reversed (eg, "x,z,-y"). The default is "x,y,z".
#rate: 3200
#   rates: 3200, 1600, 800, 400, 200, 100, 50, and 25

[resonance_tester]
accel_chip: adxl345
probe_points:
    100,100,20  # an example

[extruder]
step_pin: HermitCrab: PA6
dir_pin: !HermitCrab: PA7
enable_pin: !HermitCrab: PA5
microsteps: 16
rotation_distance: 3.45
nozzle_diameter: 0.600
filament_diameter: 1.750
heater_pin: HermitCrab: PA2
sensor_type: EPCOS 100K B57560G104F
sensor_pin: HermitCrab: PA1
control: pid
pid_Kp: 21.527
pid_Ki: 1.063
pid_Kd: 108.982
min_temp: 0
max_temp: 250

[tmc2209 extruder]
uart_pin: HermitCrab: PB0
run_current: 0.650
hold_current: 0.500
stealthchop_threshold: 999999

[fan]
pin: HermitCrab: PA3

[heater_fan hotend_fan]
pin: HermitCrab: PA4
heater: extruder
heater_temp: 50.0

#[neopixel hotend_rgb]
#pin: HermitCrab:PA8
#chain_count: 2
#color_order: GRB
#initial_RED: 0.5
#initial_GREEN: 0.5
#initial_BLUE: 0.5

[bltouch] #https://www.thingiverse.com/thing:4757657
sensor_pin: ^HermitCrab:PB2
control_pin: HermitCrab:PB1
x_offset: -35
y_offset: -6.5
z_offset: 0
probe_with_touch_mode: true

#[bed_mesh]
#speed: 120
#horizontal_move_z: 5
#mesh_min: 10,10
#mesh_max: 190, 185
#probe_count: 5,5

[safe_z_home]
home_xy_position: 120,100 # Change coordinates to the center of your print bed
speed: 50
z_hop: 10                 # Move up 10mm
z_hop_speed: 5
```

What am i doing wrong ?

grimlokason, 2021-11-21:
My bad,

The fluiddpy was not up to date.
update done, and new firmware  flashed and everything is ok !

Closed 2021-11-21.

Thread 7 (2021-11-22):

CAN Bus Failure HermitCrab

DroneMang, 2021-11-22:
Hi, reposting here from https://github.com/Klipper3d/klipper/issues/4952

The CAN bus and HermitCrab toolchanger can't connect after PSU is off for a long time, and the firmware cannot be reset, requiring a RPi reboot.

I have installed the BTT HermitCrab toolchanger using the CAN wiring scheme, overall working fine. I have a 5V PSU powering the RPi, and a separate 24V PSU on a relay that the RPi can shut on and off with the PSU plugin. If the 24V PSU is off for a long time after having connected initially, then if I try to connect the terminal gives the below output.

Also (minor issue), on initial connection, the Klipper messages say 'mcu': Unable to connect, and then eventually connects on the next line.

[klippy.zip](https://github.com/bigtreetech/HermitCrab/files/7577821/klippy.zip)

Connection closed, closing down monitor
Changing monitoring state from "Operational" to "Offline"
Changing monitoring state from "Offline" to "Opening serial connection"
Connecting to port /tmp/printer, baudrate 250000
Changing monitoring state from "Opening serial connection" to "Error"
Changing monitoring state from "Error" to "Offline after error"
Unexpected error while connecting to serial port /tmp/printer, baudrate 250000 from hook default: SerialException: '[Errno 2] could not open port /tmp/printer: [Errno 2] No such file or directory: '/tmp/printer'' @ comm.py:_open_serial:3779
Changing monitoring state from "Offline" to "Opening serial connection"
Connecting to port /tmp/printer, baudrate 250000
Changing monitoring state from "Opening serial connection" to "Error"
Changing monitoring state from "Error" to "Offline after error"
Unexpected error while connecting to serial port /tmp/printer, baudrate 250000 from hook default: SerialException: '[Errno 2] could not open port /tmp/printer: [Errno 2] No such file or directory: '/tmp/printer'' @ comm.py:_open_serial:3779
Changing monitoring state from "Offline" to "Opening serial connection"
Connecting to port /tmp/printer, baudrate 250000
Changing monitoring state from "Opening serial connection" to "Error"
Changing monitoring state from "Error" to "Offline after error"
Unexpected error while connecting to serial port /tmp/printer, baudrate 250000 from hook default: SerialException: '[Errno 2] could not open port /tmp/printer: [Errno 2] No such file or directory: '/tmp/printer'' @ comm.py:_open_serial:3779

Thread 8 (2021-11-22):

[adxl345] cfg update from Klipper commit

DroneMang, 2021-11-22:
Posting this here for users setting up.  Bigtreetech posted this: https://github.com/Klipper3d/klipper/pull/4870/commits/0718babad970a490d0cd1c4f4cbd95ebbc47237a

Make sure you add these changes to your cfg.  Thanks!

[adxl345]
cs_pin: HermitCrab: PB12
spi_bus: spi2
#spi_software_sclk_pin: HermitCrab: PB13 #Old value
#spi_software_mosi_pin: HermitCrab: PB15 #Old value
#spi_software_miso_pin: HermitCrab: PB14 #Old value
axes_map: y,z,-x

DroneMang, 2021-11-26:
last update to cfg addressed these issues and more, closing

Closed 2021-11-26.

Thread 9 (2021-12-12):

Bypass jumpers

zedn4c3r, 2021-12-12:
Add a note in the manual to remove bypass jumpers for tool ports in use.

NAPCAL, 2022-06-15:
I have mine working with all jumpers on for the tool ports.
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

p-v-n, 2022-08-29:
These jumpers simply don't even make any sense! The way the whole thing is wired is as follows:

Starting from CAN-IN plug, CANH /CANL lines go directly to A6/A7 pins (D+/D- ) respectively of female USB-C connector T0. Pins B6/B7 of this connector go to pins A6/A7 of the next USB-C connector (T1). First set of jumpers go between A6<-->B6 and A7<-->B7 pins of T0 connector. This same thing repeats for all four connectors, then B6/B7 pins of connector T3 go to CAN-OUT, while optionally connecting a terminating resistor by the the other jumper next to it.

This all would make perfect sense, *IF* USB-C cable had wires for both A and B sides of D+/D- signals. In that case, by removing the jumpers, you could make the CAN signal go to MCU through A6/A7 lines, and then return through B6/B7 lines (A6/B6 and A7/B7 are permanently connected in the receptacle on MCU side), or you could bypass the connector by leaving the jumpers on.

However, there is only one pair of wires that carries D+/D- signals in the cable, which is fine for normal USB-C functionality because the correct side will be detected by the host by looking at CC1/CC2 pins.
However, for HermitCrab case, if you remove the jumpers at connector T0, the signal will not go any further to next connector T1, and thus to terminating resistor. Also, depending on the orientation of cable plugs, may make it to MCU side, but will not be able to return (because of missing D+/D- lines for the reverse side of USB-C), or not even be able to leave the tool board.

Perhaps, I missed something, and someone can point me to where I might be wrong, but as of right now, the entire purpose of these jumpers is not really clear to me, because to make things (barely) work you must always keep them in place.

mikerocklewitz, 2022-09-10:
Schematics were uploaded the other day.

That said, it only works for me with the jumpers in place.

NAPCAL, 2022-09-10:
USB-C connector pins issue using **A6(D+)[CAN_,H], A7(D-)[CAN_L]** CAN-out from the multi-tool board and CAN-in on the Hot Mode board, and **B6(D+)[CAN_H], B7(D+)[CAN_L]** as CAN-out on the Hot Mode board and CAN-in on the multi-tool board.

While most USB-C plugs have B6(D+), & B7(D-), all cables don't have these connections (see Microchip PDF), so there will be no return to the multi-tool board. Possibly an adaptor could be made (see below) to shift the connections, but this adaptor would be needed at both ends of the cable. This is why the jumpers must be installed for the bus to be correctly terminated or continue to the CAN out connector.

Also, the Hot Mode schematics show a 120-ohm termination resistor (R17) across the CAN_H & CAN_L on that board, but that resistor is not in place on my board.

http://ww1.microchip.com/downloads/en/appnotes/00001953a.pdf

[mikerocklewitz](https://github.com/mikerocklewitz), you could make the adaptor, but you would need a second set of the breakouts you ordered.

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

mikerocklewitz, 2022-09-10:
Not sure why i would need a second set of adapters if i use a usb-c cable with the right quantity of wires....plug it into the tool board and run it to the female usb-c breakout on the skr2 side of things.  Not planning on powering anything this way just gonna run can, ground, and complete the return.

NAPCAL, 2022-09-10:
It is the only way power gets to the Tool head (hot mode board)

mikerocklewitz, 2022-09-10:
> It is the only way power gets to the Tool head (hot mode board)

Im on something totally different than what you're speaking of.

Im gonna be running a skr2 via canbus plugged into the tool board. A person can add a can transceiver to the skr board......  Power will be seperate. And the hotmode board is a whole different topic.

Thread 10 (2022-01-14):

type c can connetcor pinout

anscipione, 2022-01-14:
i can't find the pinout of type c connector of the tool board.

p-v-n, 2022-08-29:
I believe it's something similar to this: https://media.digikey.com/pdf/Data%20Sheets/Amphenol%20PDFs/C12402012-4.pdf

mikerocklewitz, 2022-09-10:
Schematics for everything have been uploaded the other day. Check github

Voodoobrew101, 2022-10-09:
It uses usb-c a-type pinout. center 2 are high low. Outside are power power like normal except thay are 24v so they will burn up a standard usb device like the BTT EBB42 boards.

Closed 2023-10-15.

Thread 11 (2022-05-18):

Missing Wiring  harness Instructions for Ender 3 v2

bsinger99, 2022-05-18:
Hi! I recently purchased a Hermit Crab & an H2 extruder for my Ender 3 v2. I'm having a problem determining how to connect the Hermit Crab to my 4.2.7 motherboard. The provided wiring harness has several unlabeled connectors and at least two (FLD & EO) which I haven't been able to determine what those acronyms refer to.

Also, the concern is that the manual has a picture of the PCB board interfaces connector wiring which doesn't match mine. The PCB-F illustration indicates that the BL TOUCH connector connects with the orange wire on the outside - mine connects with the orange wire at the other end. (Possibly it's just a mistake in the picture?)

Are there any instructions or a resource you can refer me to help me out?

aidbish, 2022-05-21:
FLD = filament detection (u can use a BTT smart filament detector
E0 = Extruder motor
the black and red floating wires are the extruder heater

rhawley88, 2023-04-03:
> FLD = filament detection (u can use a BTT smart filament detector E0 = Extruder motor the black and red floating wires are the extruder heater

I know this is a year old but how do you use the smart sensor looking for a replacement cable and haven't found. Or do I have to learn to crimp those micro connectors.  Which is fine I just have any of them in stock.

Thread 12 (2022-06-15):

BUG Missing Klipper Menuconfig bootloader option in instructions.

NAPCAL, 2022-06-15:
The current Klipper menuconfig shows the bootloader option when the current instructions does not show this option. To get the HC CAN board to work and provide a CAN bus ID, the bootloader option must be set for no bootloader.

mak0t0san, 2022-07-08:
This is very helpful.  Wasn't able to get the firmware working until I came across this.

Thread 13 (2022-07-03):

Missing board specs

mikerocklewitz, 2022-07-03:
I cant find information on the current limit for the hermit crab can....how big of a heater can i stick on the thing? Nobody has a straight answer.

@bigtreetech

cd85233, 2022-08-12:
Also how much current can the 5V source?

mikerocklewitz, 2022-09-10:
Ive been told less than 6 amps for the entire board.  No clue what the limit is for 5v only.

Schematics were uploaded the other day.

Closed 2022-09-10.

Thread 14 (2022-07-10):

Hermit Crab CAN loses connection after Klipper FIRMWARE_RESET

nberardi, 2022-07-10:
After a FIRMWARE_RESET is issued in Klipper the Hermit Crab CAN loses connection and refuses to reconnect to USB until it is put in DFU mode. This seems like a major bug and failure of the embedded system.

MarkedOne, 2022-07-12:
I too have encountered this as of a few days ago upon receiving mine.

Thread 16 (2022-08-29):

Connector type specs

runruh, 2022-08-29:
For the tool plate, it would be tremendously useful to document the connector types. Case in point: I am wiring up an orbiter v2 with filament runout which has all 4 wires and the wiring that came with it is limited to 3 even if I made an adapter for the existing cable.

Voodoobrew101, 2022-10-09:
Orbiter is only motor, that's 4 wires. Sensors are usualy 2 or 3 seperate wires?

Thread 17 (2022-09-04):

Need Schematics

mikerocklewitz, 2022-09-04:
Can you please post schematics of the the rpi canbus board and the tool board please?

Also pinouts of the rj12 and usb c ports.

Thanks

bigtreetech, 2022-09-06:
here is the  Schematics https://github.com/bigtreetech/HermitCrab/commit/faa8e65ed8a345dc4442d00cc1fcd9e4aa02fed0

Closed 2022-09-06.

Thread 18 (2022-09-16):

STEP Files do not download correctly, only show raw code.

Fickert07, 2022-09-16:
Requesting the 3d model files for the Canbus version be fixed to download correctly. Only raw text is output into the browser instead of downloaded the STEP file.

Voodoobrew101, 2022-10-09:
Save it as all types, Rename it to step.

mak0t0san, 2022-11-03:
This is not an issue with the STEP file, it's just the way GitHub handles it.  Just clone the repo onto your computer and you'll have all the files.

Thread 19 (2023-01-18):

Issue with extruder on Biqu CAN setup

sogeniusio, 2023-01-18:
I'm getting an error every time i try to extrude filament

```
Unable to obtain tmc extruder phase
TMC 'extruder' reports error: DRV_STATUS: 40140020 s2vsb=1(LowSideShort_B!) cs_actual=20 stealth=1
Once the underlying issue is corrected, use the
"FIRMWARE_RESTART" command to reset the firmware, reload the
config, and restart the host software.
Printer is shutdown

Script running error
Traceback (most recent call last):
  File "/home/pi/klipper/klippy/extras/filament_switch_sensor.py", line 58, in _exec_gcode
    self.gcode.run_script(prefix + template.render() + "\nM400")
  File "/home/pi/klipper/klippy/gcode.py", line 216, in run_script
    self._process_commands(script.split('\n'), need_ack=False)
  File "/home/pi/klipper/klippy/gcode.py", line 198, in _process_commands
    handler(gcmd)
  File "/home/pi/klipper/klippy/gcode.py", line 272, in cmd_default
    raise gcmd.error(self.printer.get_state_message()[0])
gcode.CommandError: TMC 'extruder' reports error: DRV_STATUS: 40140020 s2vsb=1(LowSideShort_B!) cs_actual=20 stealth=1
Once the underlying issue is corrected, use the
"FIRMWARE_RESTART" command to reset the firmware, reload the
config, and restart the host software.
Printer is shutdown
```

```sh
SG_RESULT: 000000ee sg_result=238
1:09 PM
PWM_AUTO: 000e0024 pwm_ofs_auto=36 pwm_grad_auto=14
1:09 PM
PWM_SCALE: 00000012 pwm_scale_sum=18
1:09 PM
PWMCONF: c80d0e24 pwm_ofs=36 pwm_grad=14 pwm_freq=1 pwm_autoscale=1 pwm_autograd=1 pwm_reg=8 pwm_lim=12
1:09 PM
DRV_STATUS: c00f0000 cs_actual=15 stealth=1 stst=1
1:09 PM
CHOPCONF: 34030053 toff=3 hstrt=5 tbl=2 vsense=1 mres=4(16usteps) intpol=1 dedge=1
1:09 PM
MSCURACT: 002300f4 cur_a=244 cur_b=35
1:09 PM
MSCNT: 000000e8 mscnt=232
1:09 PM
TSTEP: 000fffff tstep=1048575
1:09 PM
FACTORY_CONF: 0000000f fclktrim=15
1:09 PM
IOIN: 21000041 enn=1 pdn_uart=1 version=0x21
1:09 PM
OTP_READ: 0000000f otp_fclktrim=15
1:09 PM
IFCNT: 00000031 ifcnt=49
1:09 PM
GSTAT: 00000002 drv_err=1(ErrorShutdown!)
1:09 PM
GCONF: 000001c0 pdn_disable=1 mstep_reg_select=1 multistep_filt=1
1:09 PM
========== Queried registers ==========
1:09 PM
SGTHRS: 00000000
1:09 PM
TPOWERDOWN: 00000014 tpowerdown=20
1:09 PM
TPWMTHRS: 00000000
1:09 PM
IHOLD_IRUN: 0008140f ihold=15 irun=20 iholddelay=8
1:09 PM
SLAVECONF: 00000200 senddelay=2
1:09 PM
========== Write-only registers ==========
1:09 PM
DUMP_TMC STEPPER=extruder
```

remigod86, 2023-05-30:
Same here: error (GSTAT:      00000002 drv_err=1), loud "clicking" noises and klipper restarts. Could it be that the driver overheats after some time? Earlier, it started working again, until last night, when I've printed for 3 hours (when I woke up, the nozzle was stuck in the printed wall and klipper was showing extruder errors)

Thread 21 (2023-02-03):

CAN version laser setup

yzheka, 2023-02-03:
Hello. Can someone provide me instructions on how to setup diode laser? I found [klipper docs](https://github.com/Klipper3d/klipper/blob/master/docs/Using_PWM_Tools.md) about this. I connected laser to PA10 because it is not used by extruder tool. but when I add output pin for controlling laser power (as described in [config/sample-pwm-tool.cfg](https://github.com/Klipper3d/klipper/blob/master/config/sample-pwm-tool.cfg)) I get error in klipper `Firmware constant 'PWM_MAX' not found` Quick search gave that hardware pwm is not supported by mcu (results were for lpc mcu's). without hardware_pwm: true the laser is not in sync with moves, too slow

yzheka, 2024-03-12:
Yes, is working fine if you set higher pwm frequency

Closed 2024-03-12.

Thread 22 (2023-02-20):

Disparity between the step files and the actual hardware

frankbags, 2023-02-20:
So far in designing cases for the Distribution Board and the Can-Hat I have noticed that both step files for the boards are different than the actual hardware.

I'm crossing my finger that the carriage I designed fill with the dimensions provided in the step files for the dock and head step files.

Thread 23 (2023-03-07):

Unable to get HermitCrab to enter DFU mode.

Engineer997, 2023-03-07:
I cannot get the HermitCrab board to connect to my computer to flash the firmware. I have tried three different micro USB-b cables in three different ports. The board was connected to 24v with the USB-c and the computer with the micro USB-b and pressing/holding boot and clicking reset does not have any effect on the system.

gafillll, 2023-06-15:
https://www.youtube.com/watch?v=ekbxtDS_8cM&list=PLymgc_NUJTKkfN9ab8PUXw3BlwRaraVil&index=14

watch this video, it works, but takes time to understand lol.

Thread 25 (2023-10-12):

MCU 'HermitCrab' shutdown: Timer too close

lesaux, 2023-10-12:
I started seeing this on a large print. I'm using canbus.
Not sure what it is about. I had 500000 bitrate and tried reducing to 250000 to no effect.

```Stats 4938.2: gcodein=0  mcu: mcu_awake=0.160 mcu_task_avg=0.000020 mcu_task_stddev=0.000020 bytes_write=6991320 bytes_read=2034878 bytes_retransmit=0 bytes_invalid=0 send_seq=157516 receive_seq=157516 retransmit_seq=0 srtt=0.004 rttvar=0.004 rto=0.025 ready_bytes=52 upcoming_bytes=0 freq=64001027 mmu: mcu_awake=0.006 mcu_task_avg=0.000019 mcu_task_stddev=0.000014 bytes_write=306470 bytes_read=1369549 bytes_retransmit=9 bytes_invalid=0 send_seq=23295 receive_seq=23295 retransmit_seq=2 srtt=0.000 rttvar=0.000 rto=0.025 ready_bytes=0 upcoming_bytes=0 freq=48014006 adj=48012844 HermitCrab: mcu_awake=0.024 mcu_task_avg=0.000022 mcu_task_stddev=0.000031 bytes_write=2249569 bytes_read=847115 bytes_retransmit=0 bytes_invalid=0 send_seq=57675 receive_seq=57675 retransmit_seq=0 srtt=0.004 rttvar=0.002 rto=0.025 ready_bytes=30 upcoming_bytes=0 freq=47999653 adj=47998704 sd_pos=1545756 heater_bed: target=80 temp=80.1 pwm=0.183 sysload=1.37 cputime=490.279 memavail=753956 print_time=4631.496 buffer_time=2.293 print_stall=0 extruder: target=215 temp=214.8 pwm=0.433
Stats 4939.2: gcodein=0  mcu: mcu_awake=0.160 mcu_task_avg=0.000020 mcu_task_stddev=0.000020 bytes_write=6994245 bytes_read=2035380 bytes_retransmit=0 bytes_invalid=0 send_seq=157570 receive_seq=157570 retransmit_seq=0 srtt=0.003 rttvar=0.003 rto=0.025 ready_bytes=0 upcoming_bytes=0 freq=64001023 mmu: mcu_awake=0.006 mcu_task_avg=0.000019 mcu_task_stddev=0.000014 bytes_write=306532 bytes_read=1369847 bytes_retransmit=9 bytes_invalid=0 send_seq=23300 receive_seq=23300 retransmit_seq=2 srtt=0.000 rttvar=0.000 rto=0.025 ready_bytes=0 upcoming_bytes=0 freq=48014005 adj=48012969 HermitCrab: mcu_awake=0.024 mcu_task_avg=0.000022 mcu_task_stddev=0.000031 bytes_write=2250684 bytes_read=847309 bytes_retransmit=0 bytes_invalid=0 send_seq=57696 receive_seq=57696 retransmit_seq=0 srtt=0.003 rttvar=0.002 rto=0.025 ready_bytes=8 upcoming_bytes=0 freq=47999655 adj=47998706 sd_pos=1546525 heater_bed: target=80 temp=80.1 pwm=0.183 sysload=1.42 cputime=490.377 memavail=753956 print_time=4632.293 buffer_time=2.090 print_stall=0 extruder: target=215 temp=215.2 pwm=0.331
Stats 4940.2: gcodein=0  mcu: mcu_awake=0.169 mcu_task_avg=0.000020 mcu_task_stddev=0.000020 bytes_write=6998396 bytes_read=2036017 bytes_retransmit=0 bytes_invalid=0 send_seq=157645 receive_seq=157645 retransmit_seq=0 srtt=0.003 rttvar=0.003 rto=0.025 ready_bytes=44 upcoming_bytes=0 freq=64001019 mmu: mcu_awake=0.006 mcu_task_avg=0.000019 mcu_task_stddev=0.000014 bytes_write=306594 bytes_read=1370160 bytes_retransmit=9 bytes_invalid=0 send_seq=23305 receive_seq=23305 retransmit_seq=2 srtt=0.000 rttvar=0.000 rto=0.025 ready_bytes=0 upcoming_bytes=0 freq=48014004 adj=48013016 HermitCrab: mcu_awake=0.024 mcu_task_avg=0.000022 mcu_task_stddev=0.000031 bytes_write=2252251 bytes_read=847538 bytes_retransmit=0 bytes_invalid=0 send_seq=57724 receive_seq=57724 retransmit_seq=0 srtt=0.004 rttvar=0.002 rto=0.025 ready_bytes=36 upcoming_bytes=0 freq=47999648 adj=47998791 sd_pos=1547618 heater_bed: target=80 temp=80.1 pwm=0.183 sysload=1.42 cputime=490.485 memavail=753960 print_time=4633.482 buffer_time=2.279 print_stall=0 extruder: target=215 temp=215.0 pwm=0.403
Stats 4944.7: gcodein=0  mcu: mcu_awake=0.169 mcu_task_avg=0.000020 mcu_task_stddev=0.000020 bytes_write=7000256 bytes_read=2036605 bytes_retransmit=0 bytes_invalid=0 send_seq=157689 receive_seq=157686 retransmit_seq=0 srtt=0.001 rttvar=0.001 rto=0.025 ready_bytes=842 upcoming_bytes=151 freq=64001012 mmu: mcu_awake=0.005 mcu_task_avg=0.000018 mcu_task_stddev=0.000014 bytes_write=306662 bytes_read=1371153 bytes_retransmit=9 bytes_invalid=0 send_seq=23311 receive_seq=23311 retransmit_seq=2 srtt=0.000 rttvar=0.000 rto=0.025 ready_bytes=0 upcoming_bytes=0 freq=48014003 adj=48013109 HermitCrab: mcu_awake=0.022 mcu_task_avg=0.000022 mcu_task_stddev=0.000031 bytes_write=2253165 bytes_read=847931 bytes_retransmit=0 bytes_invalid=0 send_seq=57749 receive_seq=57746 retransmit_seq=0 srtt=0.001 rttvar=0.001 rto=0.025 ready_bytes=203 upcoming_bytes=47 freq=47999636 adj=47998765 sd_pos=1548267 heater_bed: target=80 temp=80.2 pwm=0.120 sysload=1.71 cputime=490.598 memavail=754092 print_time=4634.179 buffer_time=0.000 print_stall=0 extruder: target=215 temp=214.9 pwm=0.433
- - TRACE: Processing idle_timeout 'ready' event
MCU 'HermitCrab' shutdown: Timer too close
clocksync state: mcu_freq=48000000 last_clock=222508611506 clock_est=(4912.129 220947035299 47999636.459) min_half_rtt=0.000225 min_rtt_time=3212.466 time_avg=4912.129(941.802) clock_avg=220947035299.966(45206152803.844) pred_variance=45354636.411 clock_adj=(-0.036 47998670.500)
Dumping serial stats: bytes_write=2253221 bytes_read=847955 bytes_retransmit=0 bytes_invalid=0 send_seq=57750 receive_seq=57748 retransmit_seq=0 srtt=0.002 rttvar=0.001 rto=0.025 ready_bytes=199 upcoming_bytes=0
Dumping send queue 100 messages
Sent 0 4937.339547 4937.338739 14: seq: 10, tmcuart_send oid=0 write=b'\xea\x03( \xc3' read=10
Sent 1 4937.353960 4937.350616 58: seq: 11, queue_step oid=1 interval=153642 count=1 add=0, queue_step oid=1 interval=294463 count=1 add=0, queue_step oid=1 interval=211099 count=1 add=0, queue_step oid=1 interval=134761 count=2 add=-25446, queue_step oid=1 interval=102483 count=8 add=0, queue_step oid=1 interval=106181 count=2 add=26065, queue_step oid=1 interval=195664 count=1 add=0
Sent 2 4937.357164 4937.350616 59: seq: 12, queue_step oid=1 interval=305771 count=1 add=0, queue_step oid=1 interval=159059 count=2 add=-28186, queue_step oid=1 interval=129115 count=3 add=1235, queue_step oid=1 interval=171320 count=1 add=0, queue_step oid=1 interval=312880 count=1 add=0, queue_step oid=1 interval=178508 count=1 add=0, queue_step oid=1 interval=125417 count=2 add=-19673
Sent 3 4937.360588 4937.350616 60: seq: 13, queue_step oid=1 interval=102423 count=8 add=0, queue_step oid=1 interval=110836 count=2 add=31931, queue_step oid=1 interval=244009 count=2 add=20398, queue_step oid=1 interval=144713 count=2 add=-13938, queue_step oid=1 interval=130026 count=2 add=0, queue_step oid=1 interval=135672 count=1 add=0, queue_step oid=1 interval=199032 count=1 add=0
Sent 4 4937.364092 4937.356841 63: seq: 14, queue_step oid=1 interval=303738 count=1 add=0, queue_step oid=1 interval=158236 count=1 add=0, queue_step oid=1 interval=117870 count=2 add=-14035, queue_step oid=1 interval=102482 count=8 add=0, queue_step oid=1 interval=118178 count=1 add=0, queue_step oid=1 interval=156078 count=1 add=0, queue_step oid=1 interval=300437 count=1 add=0, queue_step oid=1 interval=203897 count=1 add=0
Sent 5 4937.367436 4937.359960 58: seq: 15, queue_step oid=1 interval=135712 count=2 add=-4999, queue_step oid=1 interval=129962 count=2 add=0, queue_step oid=1 interval=143916 count=1 add=0, queue_step oid=1 interval=251897 count=2 add=4816, queue_step oid=1 interval=152623 count=3 add=-1634, queue_step oid=1 interval=185397 count=1 add=0, queue_step oid=1 interval=409774 count=1 add=0
Sent 6 4937.370812 4937.363107 59: seq: 16, queue_step oid=1 interval=185200 count=1 add=0, queue_step oid=1 interval=127609 count=2 add=-21107, queue_step oid=1 interval=102452 count=10 add=0, queue_step oid=1 interval=114537 count=1 add=0, queue_step oid=1 interval=148563 count=1 add=0, queue_step oid=1 interval=307273 count=2 add=11500, queue_step oid=1 interval=155417 count=2 add=-4297
Sent 7 4937.374252 4937.367594 61: seq: 17, queue_step oid=1 interval=149619 count=2 add=26494, queue_step oid=1 interval=313269 count=1 add=0, queue_step oid=1 interval=175193 count=1 add=0, queue_step oid=1 interval=124299 count=2 add=-18874, queue_step oid=1 interval=102482 count=8 add=0, queue_step oid=1 interval=112009 count=2 add=32164, queue_step oid=1 interval=255662 count=2 add=-3033
Sent 8 4937.377596 4937.371223 58: seq: 18, queue_step oid=1 interval=143042 count=2 add=-12376, queue_step oid=1 interval=129916 count=2 add=0, queue_step oid=1 interval=136452 count=1 add=0, queue_step oid=1 interval=204010 count=1 add=0, queue_step oid=1 interval=299831 count=1 add=0, queue_step oid=1 interval=155888 count=1 add=0, queue_step oid=1 interval=116881 count=2 add=-13260
Sent 9 4937.553379 4937.552127 22: seq: 19, queue_digital_out oid=12 clock=3135895318 on_ticks=1532332, queue_step oid=1 interval=102423 count=8 add=0
Sent 10 4937.683490 4937.683126 6: seq: 1a, get_clock
Sent 11 4937.728010 4937.724918 56: seq: 1b, queue_step oid=1 interval=119258 count=1 add=0, queue_step oid=1 interval=158305 count=1 add=0, queue_step oid=1 interval=303897 count=1 add=0, queue_step oid=1 interval=198823 count=1 add=0, queue_step oid=1 interval=134887 count=2 add=-4112, queue_step oid=1 interval=130026 count=2 add=0, queue_step oid=1 interval=145530 count=1 add=0
Sent 12 4937.731434 4937.724918 60: seq: 1c, queue_step oid=1 interval=263319 count=2 add=-18436, queue_step oid=1 interval=141234 count=2 add=-29076, queue_step oid=1 interval=102365 count=8 add=0, queue_step oid=1 interval=104221 count=2 add=22713, queue_step oid=1 interval=178615 count=1 add=0, queue_step oid=1 interval=313002 count=1 add=0, queue_step oid=1 interval=171333 count=1 add=0
Sent 13 4937.734606 4937.724918 58: seq: 1d, queue_step oid=1 interval=130400 count=4 add=0, queue_step oid=1 interval=160065 count=1 add=0, queue_step oid=1 interval=306099 count=1 add=0, queue_step oid=1 interval=195387 count=1 add=0, queue_step oid=1 interval=130644 count=2 add=-23027, queue_step oid=1 interval=102423 count=8 add=0, queue_step oid=1 interval=107809 count=2 add=28471
Sent 14 4937.737918 4937.729727 57: seq: 1e, queue_step oid=1 interval=211282 count=1 add=0, queue_step oid=1 interval=294114 count=1 add=0, queue_step oid=1 interval=152366 count=2 add=-21700, queue_step oid=1 interval=129069 count=3 add=1694, queue_step oid=1 interval=181226 count=1 add=0, queue_step oid=1 interval=312492 count=1 add=0, queue_step oid=1 interval=169240 count=1 add=0
Sent 15 4937.741326 4937.734745 60: seq: 1f, queue_step oid=1 interval=122161 count=2 add=-17353, queue_step oid=1 interval=102482 count=8 add=0, queue_step oid=1 interval=113984 count=2 add=32629, queue_step oid=1 interval=276366 count=1 add=0, queue_step oid=1 interval=232225 count=1 add=0, queue_step oid=1 interval=140330 count=2 add=-9661, queue_step oid=1 interval=129918 count=2 add=0
Sent 16 4937.744830 4937.737115 63: seq: 10, queue_step oid=1 interval=138433 count=1 add=0, queue_step oid=1 interval=215608 count=1 add=0, queue_step oid=1 interval=290663 count=1 add=0, queue_step oid=1 interval=151760 count=1 add=0, queue_step oid=1 interval=115129 count=2 add=-11695, queue_step oid=1 interval=102482 count=8 add=0, queue_step oid=1 interval=121602 count=1 add=0, queue_step oid=1 interval=163159 count=1 add=0
Sent 17 4937.748206 4937.742341 59: seq: 11, queue_step oid=1 interval=309109 count=1 add=0, queue_step oid=1 interval=189755 count=1 add=0, queue_step oid=1 interval=132889 count=3 add=-1857, queue_step oid=1 interval=129912 count=2 add=19592, queue_step oid=1 interval=280757 count=1 add=0, queue_step oid=1 interval=226705 count=1 add=0, queue_step oid=1 interval=138171 count=2 add=-27374
Sent 18 4938.092479 4938.089135 58: seq: 12, queue_step oid=1 interval=102482 count=8 add=0, queue_step oid=1 interval=105107 count=2 add=24246, queue_step oid=1 interval=185945 count=1 add=0, queue_step oid=1 interval=310864 count=1 add=0, queue_step oid=1 interval=164433 count=2 add=-32668, queue_step oid=1 interval=129916 count=3 add=0, queue_step oid=1 interval=165475 count=1 add=0
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

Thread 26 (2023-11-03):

Thermistor error "Heater extruder not heating at expected rate"

Phil1988, 2023-11-03:
Can be closed, it appears that this was caused by a faulty thermistor cable

Closed 2023-11-14.

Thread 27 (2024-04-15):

Hermit Crab 2 and Failed Probe port

5teveO, 2024-04-15:
This may be a bit long winded.. but here goes.

I got a hermit crab V2 canbus from BTT a few weeks back. Flashed it with Katapult and then klipper and all was good from a firmware point of view. I have spent a bit of time building the rest of the machine up and there was a lot of wiring to do as there are a lot of btt external 5160 drivers, PSU control etc.  Intention is to have a biqu microprobe running on the tool heads too (im coming from a canbus hermit crab 1)

Finally got to power the machine on and start configuration.. that all went fine too. Config was easy as it was a swap from an skr1.4t and hermit crab v1 canbus to an octopus pro 1.1 and hermit crab V2 canbus..

Started testing the microprobe - which worked very well on previous Hermit crab V1 - and I could not get it to deploy or to retract - which was strange as it worked fine with an identical config (excpet with pins changed to suit HC v2) - swapped probes, cables and even tool plates to see if any of those was an issue. Nothing.

Confirmed 5v was present, and then started testing the GPIO pins so did the query_probe in klipper with the following results - I did this for both GPIO24 being set up as the sensor pin and also with GPIO23 being setup as sensor pin
GPIO24 open -  triggered
GPIO24 shorted to ground -  triggered
GPIO23 open -  triggered
GPIO23 shorted to ground -  triggered

No change in state for either GPIO pins.

To confirm I also set up a BLTouch - same thing - on power up - self tests - then pin up / down does nothing and query probe shows open regardless of whether the pin is up or down.

Would it be possible to give me some guidance as to what else could be wrong?

With no schematics available (nor step files etc) I cannot really do any more troubleshooting.

I've been guided though this by JamesH on the Klipper discord.. @bigtreetech

If anymore info is required.. please advise asap as I need to get this machine up and running.

Steve

5teveO, 2024-04-15:
Ok i have investigated this a bit more by testing the GPIO's as best I can. It appears that GPIO22,23 and 24 are all non operational - I cannot heat the hot end and deploy / sense the probe.

GPIO 27/28 work and show correct temps
GPIO14 runs FAN1 ok
CAN communicates ok as far as I know so thats GPIO4/5
LIS2DW communicates too - so thats GPIO0/1 working.
I cant prove motor at the moment but will try to do that at some point.

Where do I go from here. Pretty Sad about it as the HC1 Canbus has been brilliant.

Steve

LancAir390, 2024-04-22:
Were you able to solve your issue?

Like you I had my microprobe working great with Hermit Crab CANbus v1, but have had no luck with Hermit Crab Can 2.

As an aside my hot end does heat up correctly.

I may have to return this one to Amazon marked as defective...

5teveO, 2024-04-23:
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

Nope - Conclusion was that the 3 gpio pins are dead for some reason. I received an emal from @bigtreetech Last Wednesday - to which I replied to.. and so far nothing - no response. As i bought it from the Biqu site I dont have the option to just return it, so If I dont get a response in a a few more days - or at least an update from them - I'll be exploring doing a chargeback from the credit card. I cant have my printer down for much longer and dont expect a week between emails.

I'd see if you can do some of the testing I did to prove the GPIO is dead. Did you copy the probe stuff from your HC1 config and change the pin numbers? Is your Microprobe a v1 or v2? Have you tested the probe on another machine? Happy to take a look if it helps... but i assume you know what you are doing... !

lotfinoluffy, 2024-05-26:
have the same issues, so think the board are faulty

lotfinoluffy, 2024-05-26:
have the same issues, so think the board are faulty, on both boards that ive ordered, and as usual no reply from the great renowned btt (add sarcasm here)
just wondering @5teveO if you happen to test the filament runout sensor since i didnt see the pin number in github or the config file, thanks

kasuke5, 2024-09-09:
Hello there, I find the documentation really not clear at all.
I've struggled to make everything works and like all of you I came from Hermitcrab1 which was working ... Until I don't really know what happened, but I tried to plug in board to the main one and the hooks just touch the circuit board and I think burn the main card... (and you can't buy this card anywhere, smart move btt)

Anyway, I've struggled to understand that you actually have a switch button for thermal sensor, even what's inside the package seems to be less than the v1, you only have cables, no jumper, no crimping tools etc ...

So my 3Dtouch was working fine with v1, now it only can pin_up and down but cannot read the sensor values, resulting with no way to home.

I tried using the provided cables, but it's the exact same than previous one.

looxonline, 2024-09-10:
> To confirm I also set up a BLTouch - same thing - on power up - self tests - then pin up / down does nothing and query probe shows open regardless of whether the pin is up or down.

May I suggest that you try to use an endstop port for the probe trigger value instead of the probe pin. I believe that may work.

looxonline, 2024-09-10:
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

Did you have a pull up enabled on GPIO23 when running this test?

vogll, 2025-02-18:
I can confirm that the Hermit Crab V2 Canbus is distributed with a defective BLTouch circuit. I have sent four emails to support, including a video and a description of the problem. BIQU support confirmed the defective circuit and promised to send a new one. But after three months... nothing. BLTouch is not supported in this version of the Hermit Crab. Don't buy it!

bigtreetech, 2025-02-18:
> I can confirm that the Hermit Crab V2 Canbus is distributed with a defective BLTouch circuit. I have sent four emails to support, including a video and a description of the problem. BIQU support confirmed the defective circuit and promised to send a new one. But after three months... nothing. BLTouch is not supported in this version of the Hermit Crab. Don't buy it!

BIQU here. Can confirm that the circuit is not defective. Please post pics of your removable board(s) and in specific the area where the probe port is located.

vogll, 2025-02-18:
Behaviour of the probe is the same as described at the previous postsby SteveO.

Sensor_pin of the Hermit Crab doesn't read properly BLTouch output (Sensor pin). After sending homing Command (G28) BLtouch retract sensor but after some seconds Klipper return errors

8:37 BLTouch failed to raise probe
8:37 Failed to verify BLTouch probe is raised; retrying.
8:37 Failed to verify BLTouch probe is raised; retrying.

Here is the another communication from the Clipper

8:40 probe: TRIGGERED
8:40 QUERY_PROBE
8:39 Sending BLTOUCH_DEBUG COMMAND=touch_mode
8:39 BLTOUCH_DEBUG COMMAND=touch_mode
8:39 Sending BLTOUCH_DEBUG COMMAND=pin_down
8:39 BLTOUCH_DEBUG COMMAND=pin_down
8:39 probe: TRIGGERED
8:38 QUERY_PROBE

Here is sniped of my Klipper config file

[bltouch]
sensor_pin:  ^hermitcrab2:gpio24
control_pin: hermitcrab2:gpio23
z_offset : 2.41

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

Thijskunst, 2025-03-09:
Im having the same issue on my hermit crab v2. It seems that the flyback diode  D3 on all 3 of my removable tool boards have failed open circuit. D3 on my unused spare board has been open circuit from the factory.  D3 is there to protect the gpio pin from the reverse voltage spike from turning off the  probe.

I don't think it's a problem with the circuit, I think its an issue with cheap, dodgy parts that have a high failure rate.

I've contacted BTT on AliExpress, where I bought my hermit crab v2, but haven't heard back from them yet.

vogll, 2025-04-13:
After 4 months Biqu sent me new Hermit Crab board. BLtouch working as expected. However, the correct settings are not the ones posted by BigTreeTech, but rather:

```
[bltouch]
sensor_pin: ^hermitcrab2:gpio24
control_pin: hermitcrab2:gpio23
```

lotfinoluffy, 2025-07-24:
@bigtreetech doesn't change anything, and the ... if it was the correct one why is it the same as @vogll
any of those configs and you get the probe on the triggered state whether the pin is up or down

ordered 2 units and what a PAAAAAAAIN it was and none of them is working and the support dare with no shame shift every single blame on me when its your selling faulty boards

also blotch or eddy coil, the probe also gives a Unable to obtain 'i2c_read_response' response or a shutdown: I2C START READ NACK with your config and no matter what it doesn't work

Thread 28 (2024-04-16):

Step Files still not available for Metalwork Hermit Crab V2

5teveO, 2024-04-16:
It was bought up on the facebook group that STEP files of the die castings for the Hermit Crab V2 etc were not yet available only step files of the boards. It was said that it would be bought up and rectified shortly.

Several week on and still no step files

Also strill no resolution to the matter that there are not enough cable sets provided. the Hermit Crab v1 comes with a cable set per tool plate - stepper cable, probe cable and Runout sensor cable. 3 cables of each type (one per tool plate)

Hermit crab V2 comes with 3 tool plates and only one set of cables - this also was meant to be being resolved according to the facebook group.

I've been generally happy with BTT products (Hermit crab 1 was very good) however i'm feeling a bit of regret at buying the hermit crab V2 currently

Steve

5teveO, 2024-04-23:
For those of you looking for a 3d model of the Hermit Crab V2 Canbus I have finalised the models - The PCBS were created by BTT and can be found in the hermit crab git.

https://grabcad.com/library/btt-hermit-crab-v2-canbus-1

https://www.printables.com/model/852257-btt-hermit-crab-v2-canbus

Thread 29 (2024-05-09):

Hermit Crab V2 Step/Stl File.

johnwilling, 2024-05-09:
I see version 1 Cad/Step/Stl files are available at https://github.com/bigtreetech/HermitCrab but there are no available files for the Version 2.0 of the hermit Crab.  I'm looking to fit it to my Anycubic I3 Mega Pro and need to build a plate to attach it to the X-Carriage.

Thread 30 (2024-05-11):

Hermit Crab 2 M V1.0 - aluminum plate STL/STEP

irebane, 2024-05-11:
May we please have original STEP file of aluminum plate so we could design things around it instead of wasting time and designing something that you guys already designed?
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

lotfinoluffy, 2024-05-26:
everyones waiting for those, so someone had the great idea to make them instead of waiting forever for btt, goooood .... the support is just horrible with this company

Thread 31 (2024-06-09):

HC2 CAN & MicroProbe 2 Issues

Aiden636, 2024-06-09:
MCU: Manta M8P v2.0 & CB1
Printer: ender 3 (this thing will live forever)
Head: HermitCrab 2 Can / H2 V2S Revo / MicroProbe 2

I have set every thing up and have come down to these final issues. The probe will not deploy with macros and the HE temp is showing -80C+. I have a feeling the the HC2 might have some issues.

Of note, when printer starts, the probe does the self check.

Anyone else have this issue?

Aiden636, 2024-06-09:
[All Config.txt](https://github.com/user-attachments/files/15753887/All.Config.txt)
Here's all pertinent configs
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

Aiden636, 2024-06-09:
I have also swapped out the toolhead (1 of 3 shipped) no difference in problems.

Aiden636, 2024-06-11:
I am big dumb. Had to flip the thermistor dip to NTC 100k. fixed I guess.

Closed 2024-06-11.

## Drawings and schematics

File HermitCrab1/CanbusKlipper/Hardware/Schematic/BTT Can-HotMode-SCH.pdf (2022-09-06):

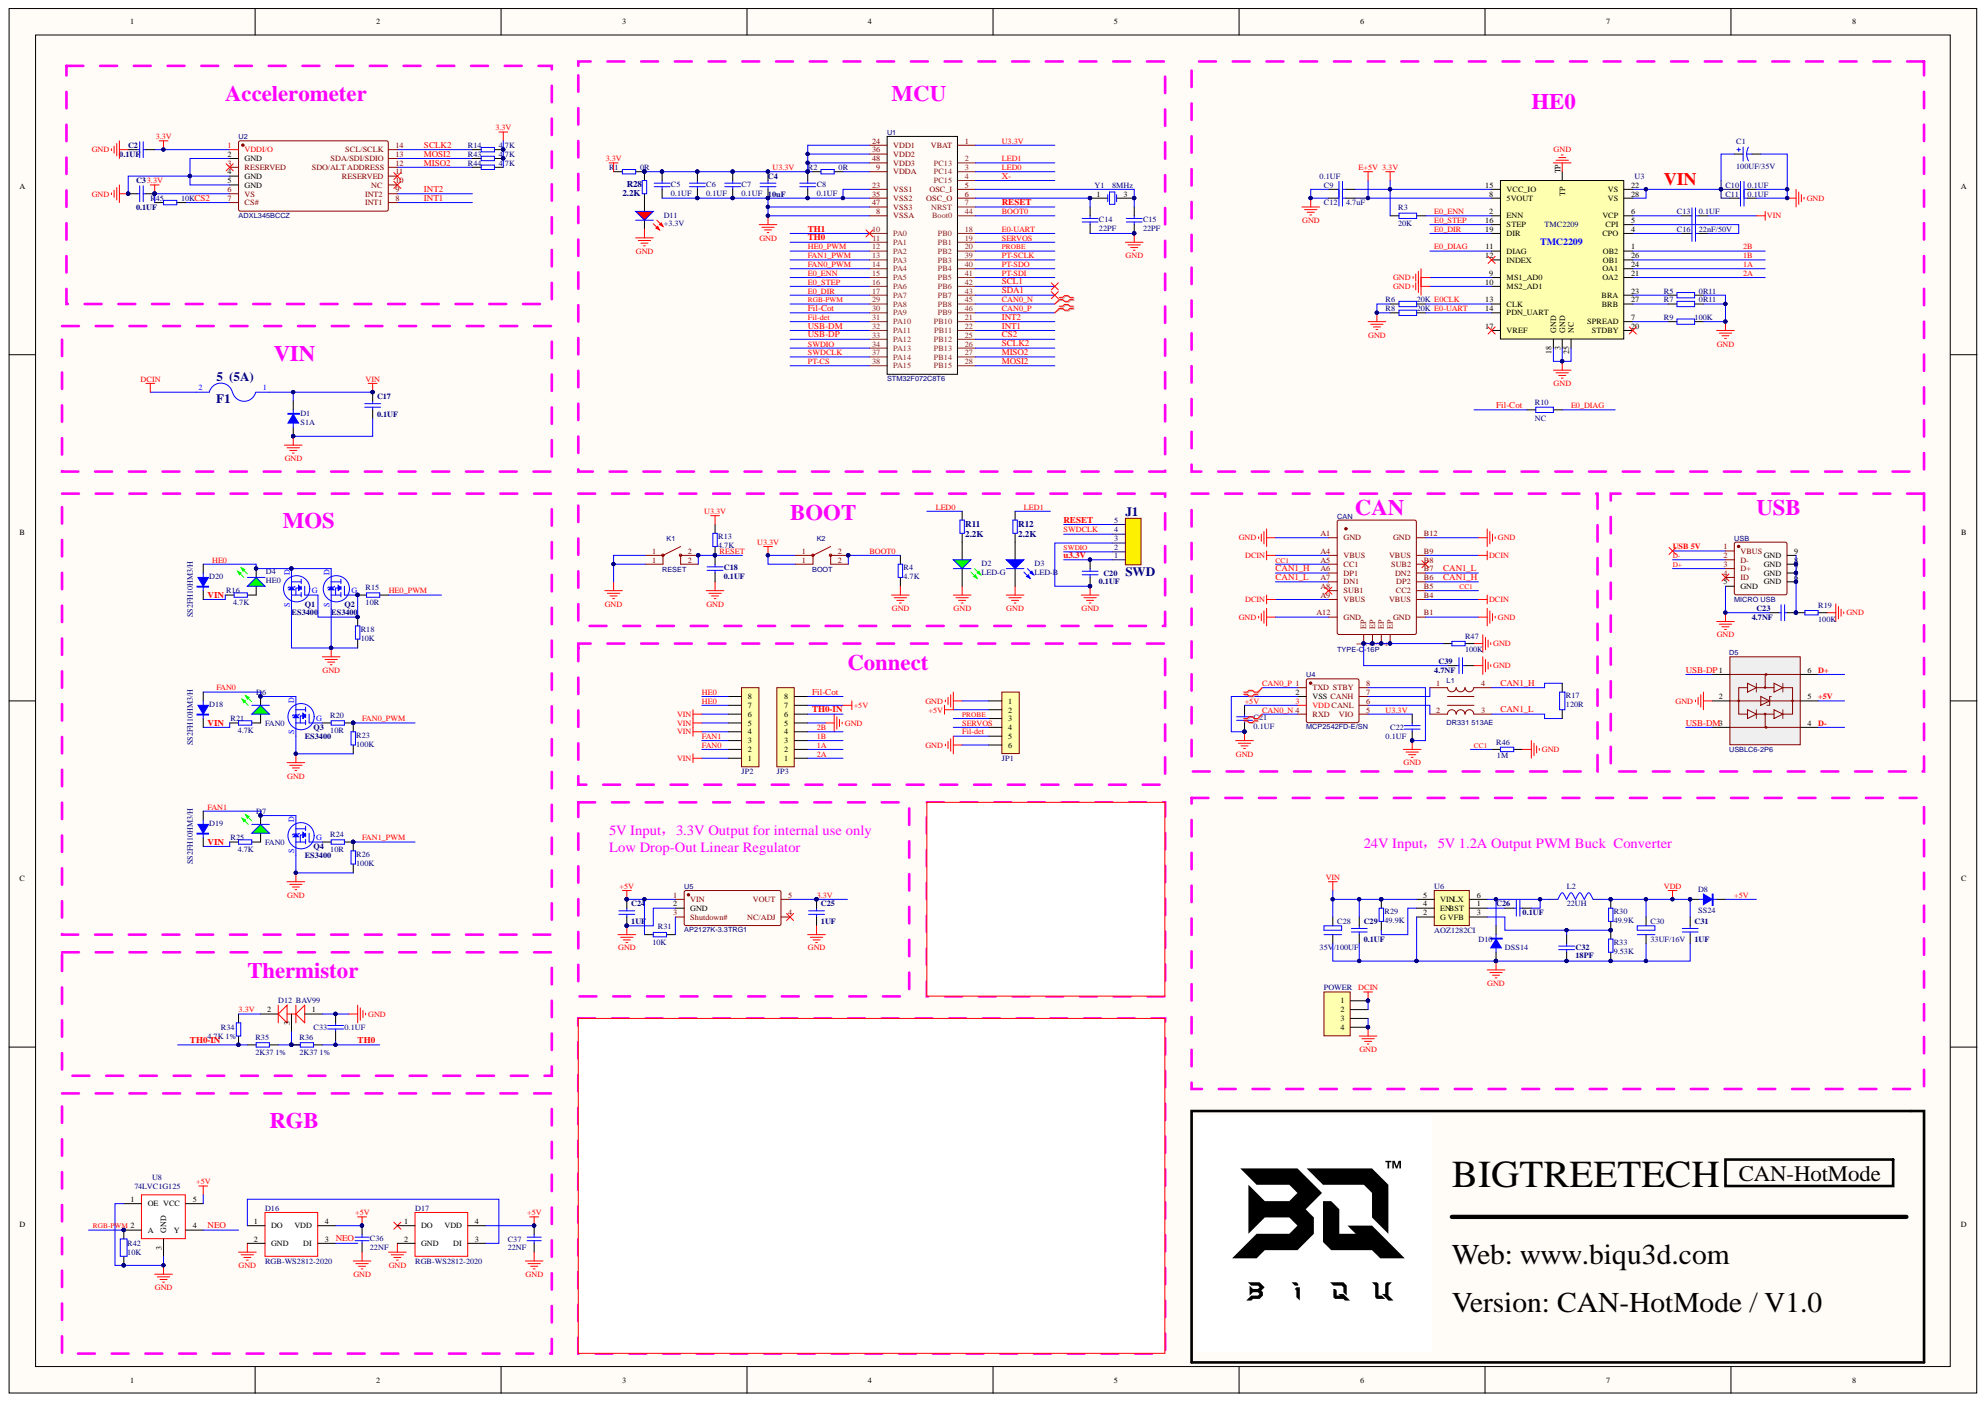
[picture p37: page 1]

SWDIO | 2

24V Input，5V 1.2A Output PWM Buck Converter 5V Input，3.3V Output for internal use only
Low Drop-Out Linear Regulator

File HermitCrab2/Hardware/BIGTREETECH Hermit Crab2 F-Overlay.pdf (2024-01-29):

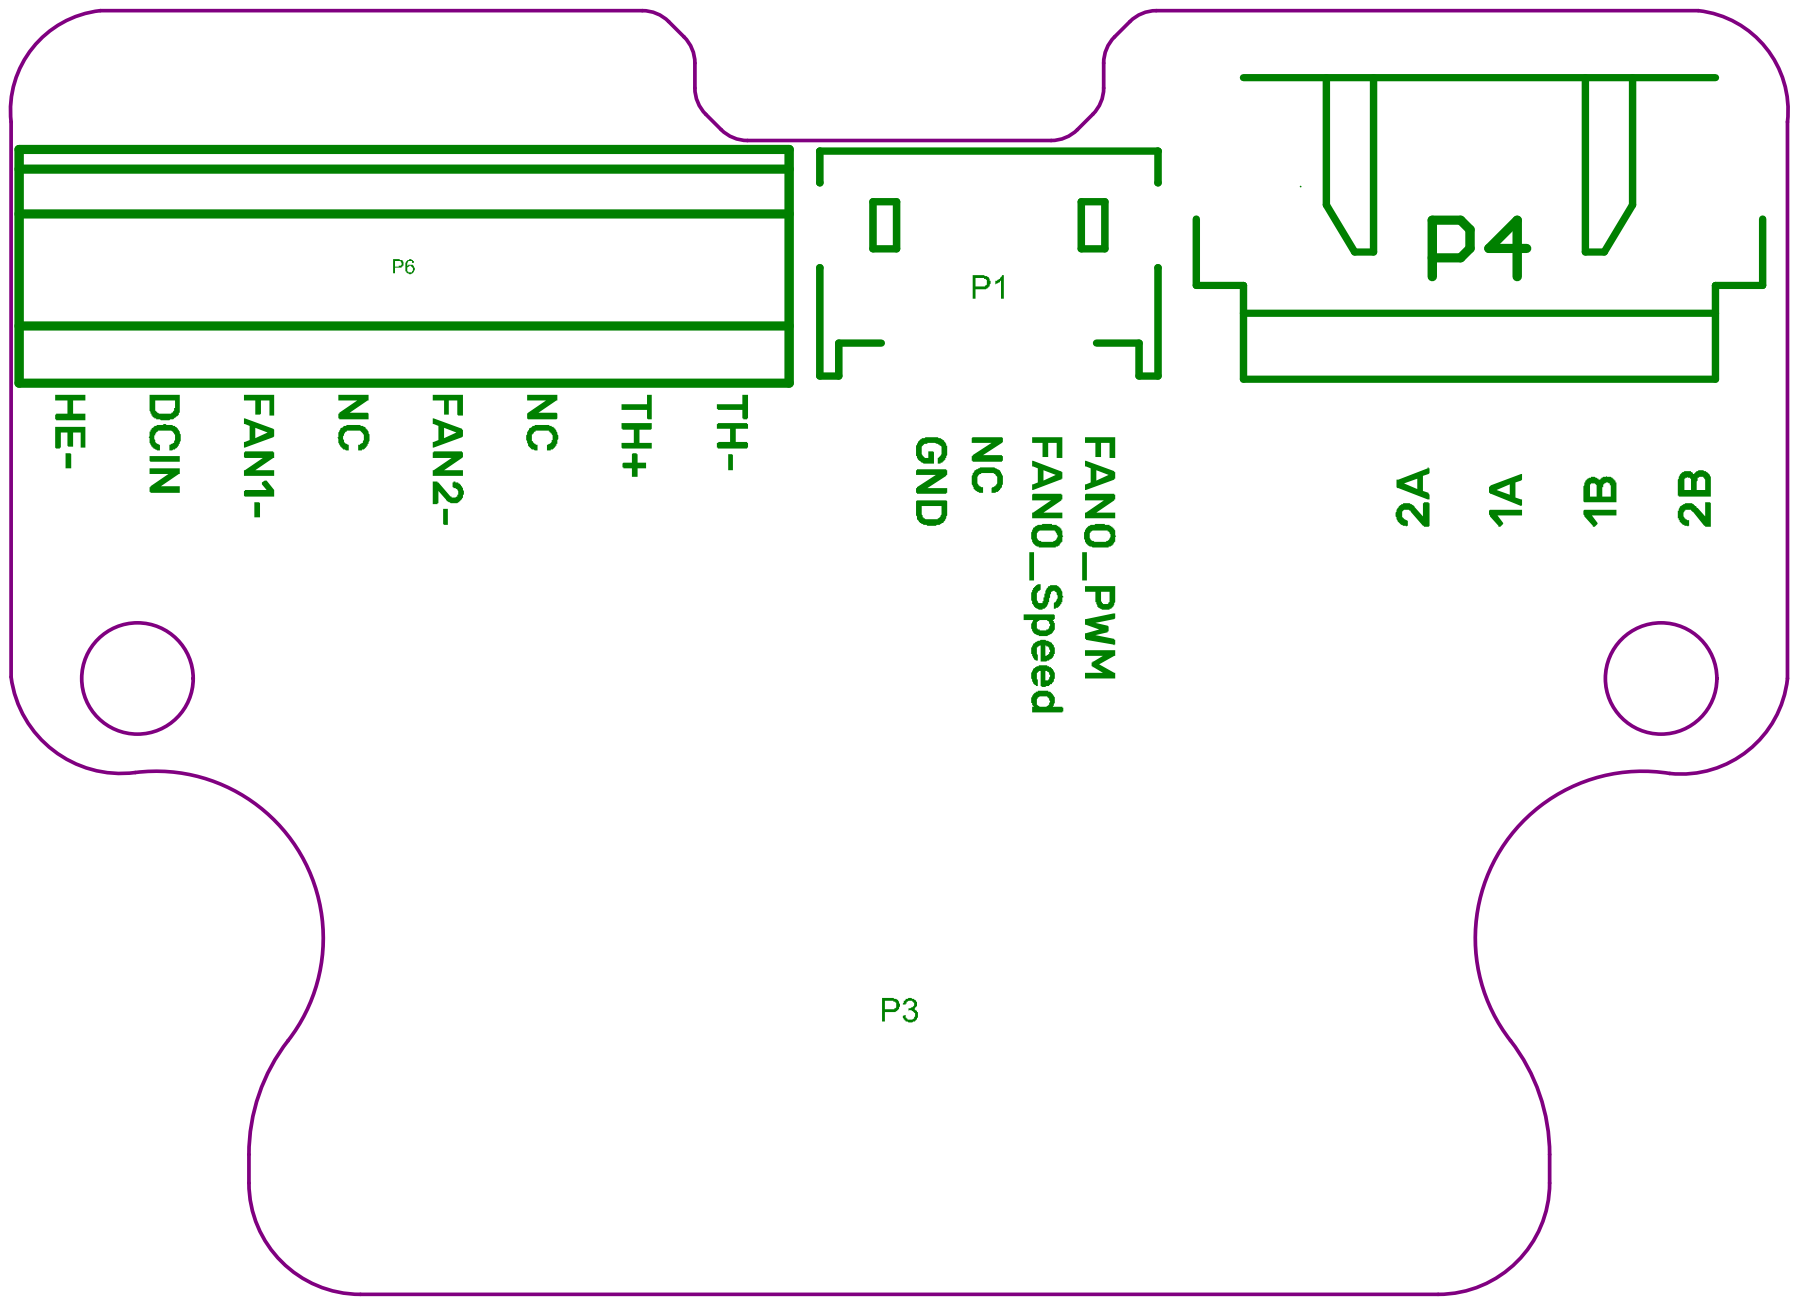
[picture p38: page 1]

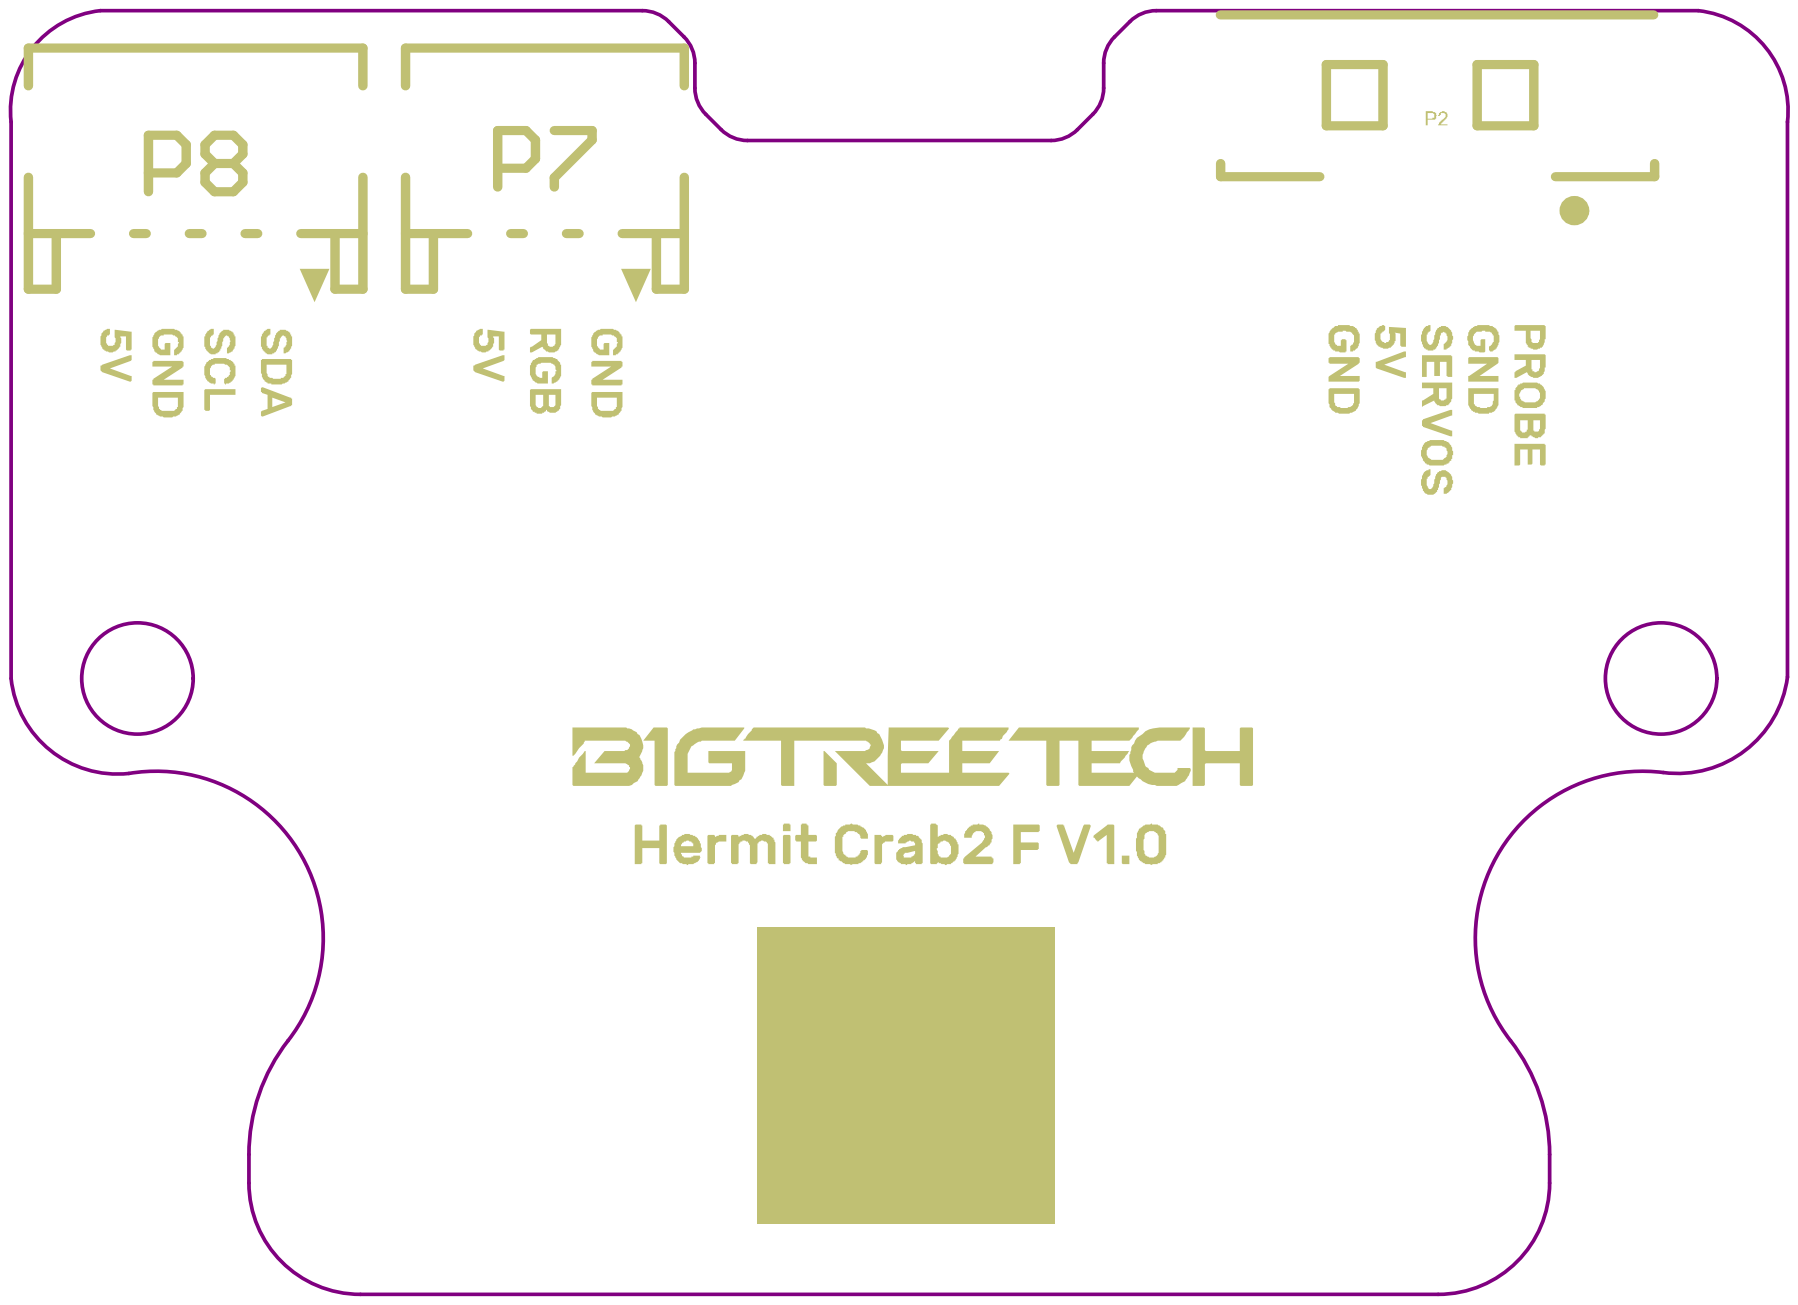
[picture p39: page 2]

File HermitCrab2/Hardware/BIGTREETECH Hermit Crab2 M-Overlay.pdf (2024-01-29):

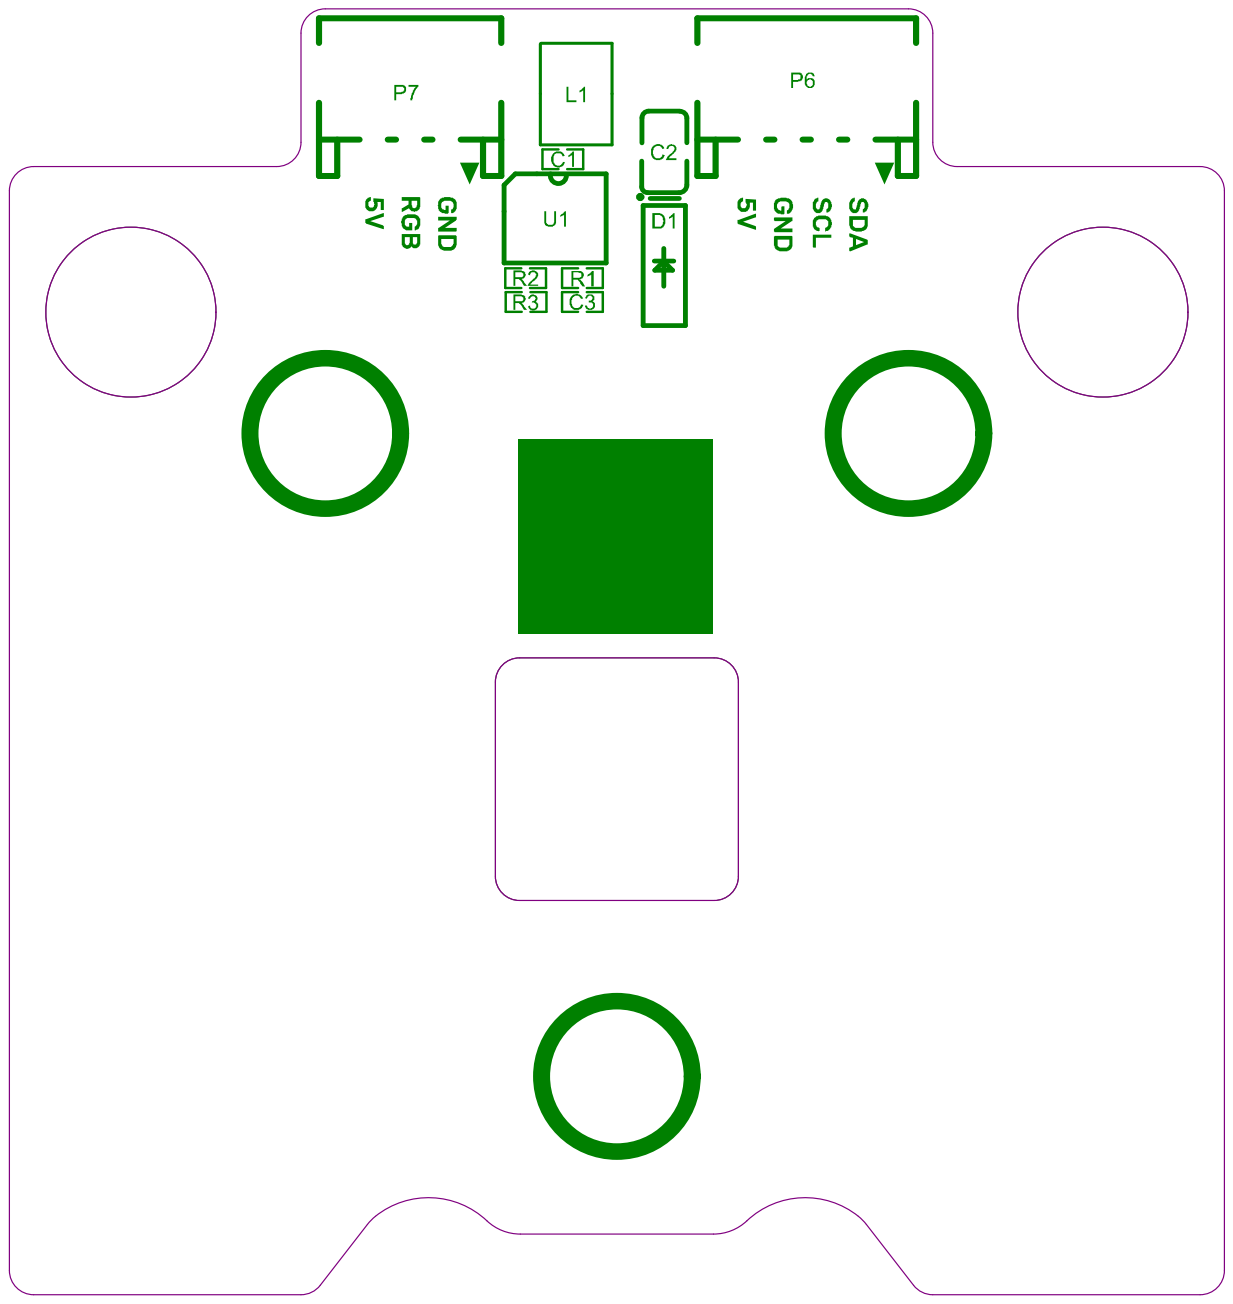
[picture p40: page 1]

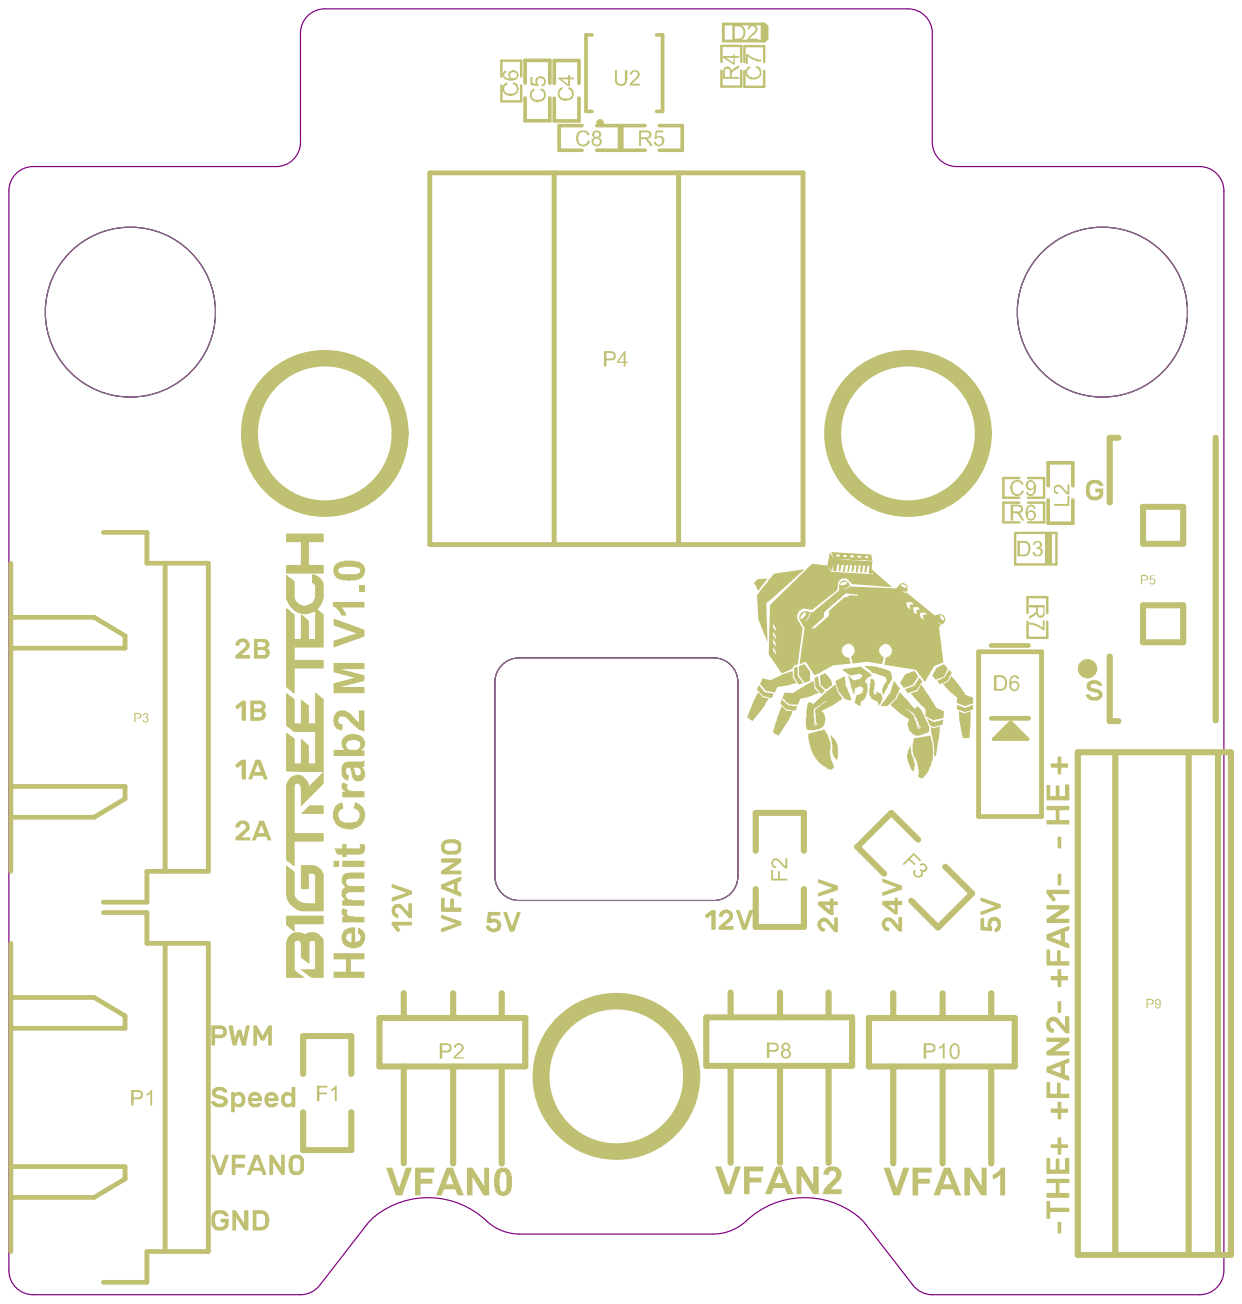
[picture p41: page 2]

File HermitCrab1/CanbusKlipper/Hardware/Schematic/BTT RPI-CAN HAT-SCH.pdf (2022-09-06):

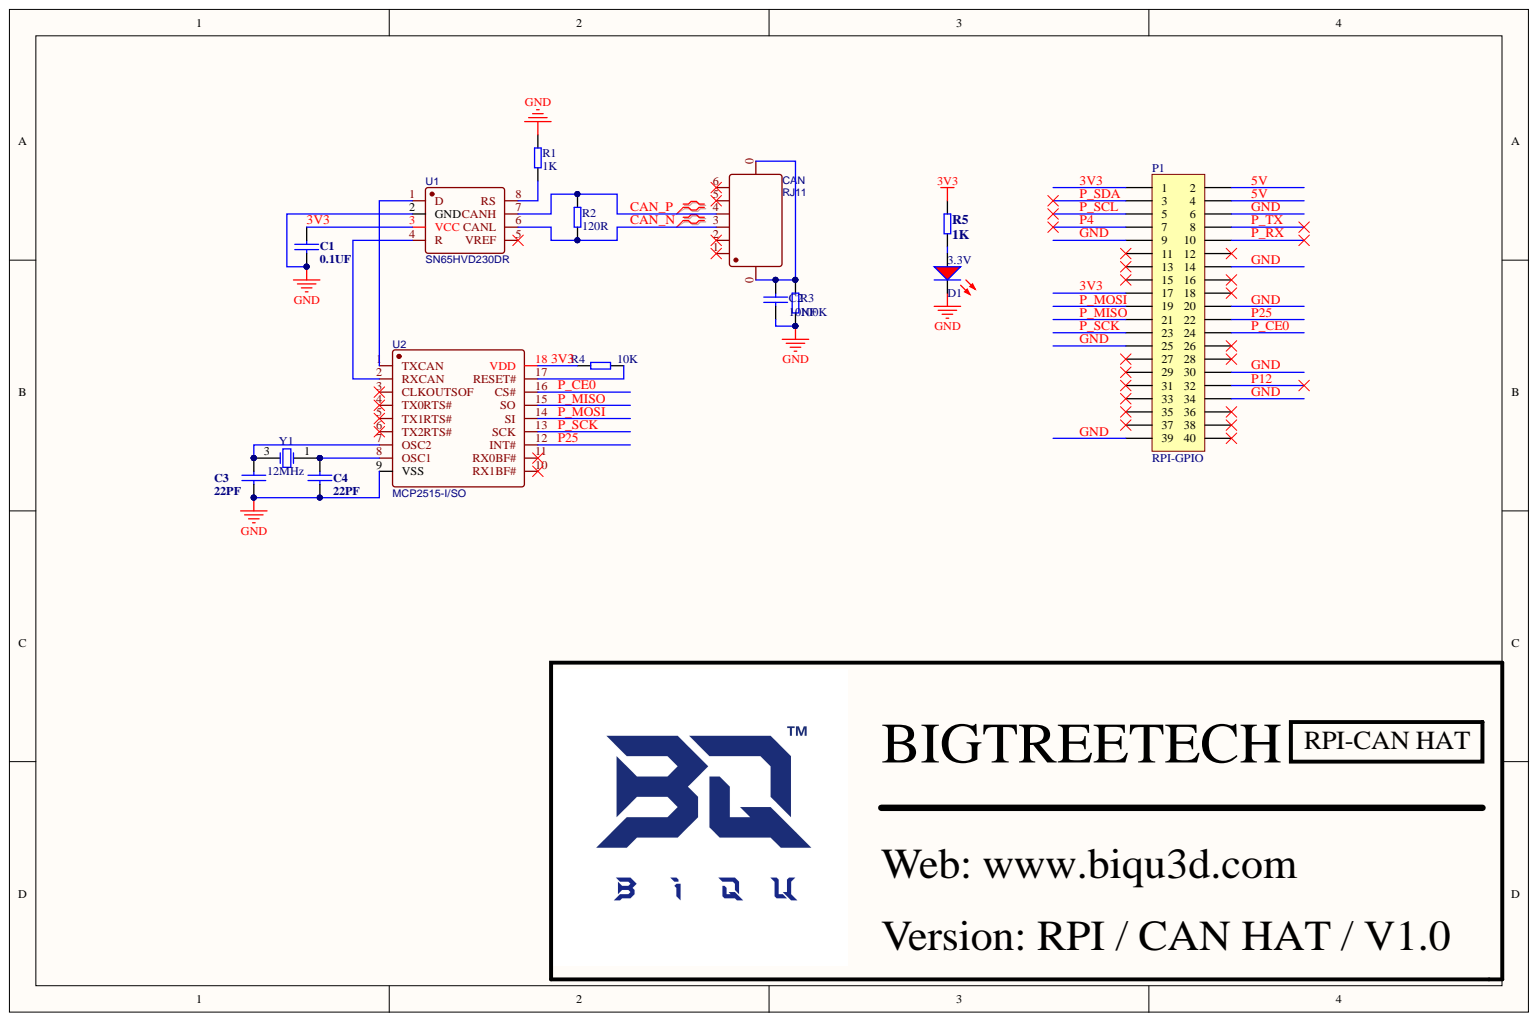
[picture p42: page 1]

Web: www.biqu3d.com
Version: RPI / CAN HAT / V1.0

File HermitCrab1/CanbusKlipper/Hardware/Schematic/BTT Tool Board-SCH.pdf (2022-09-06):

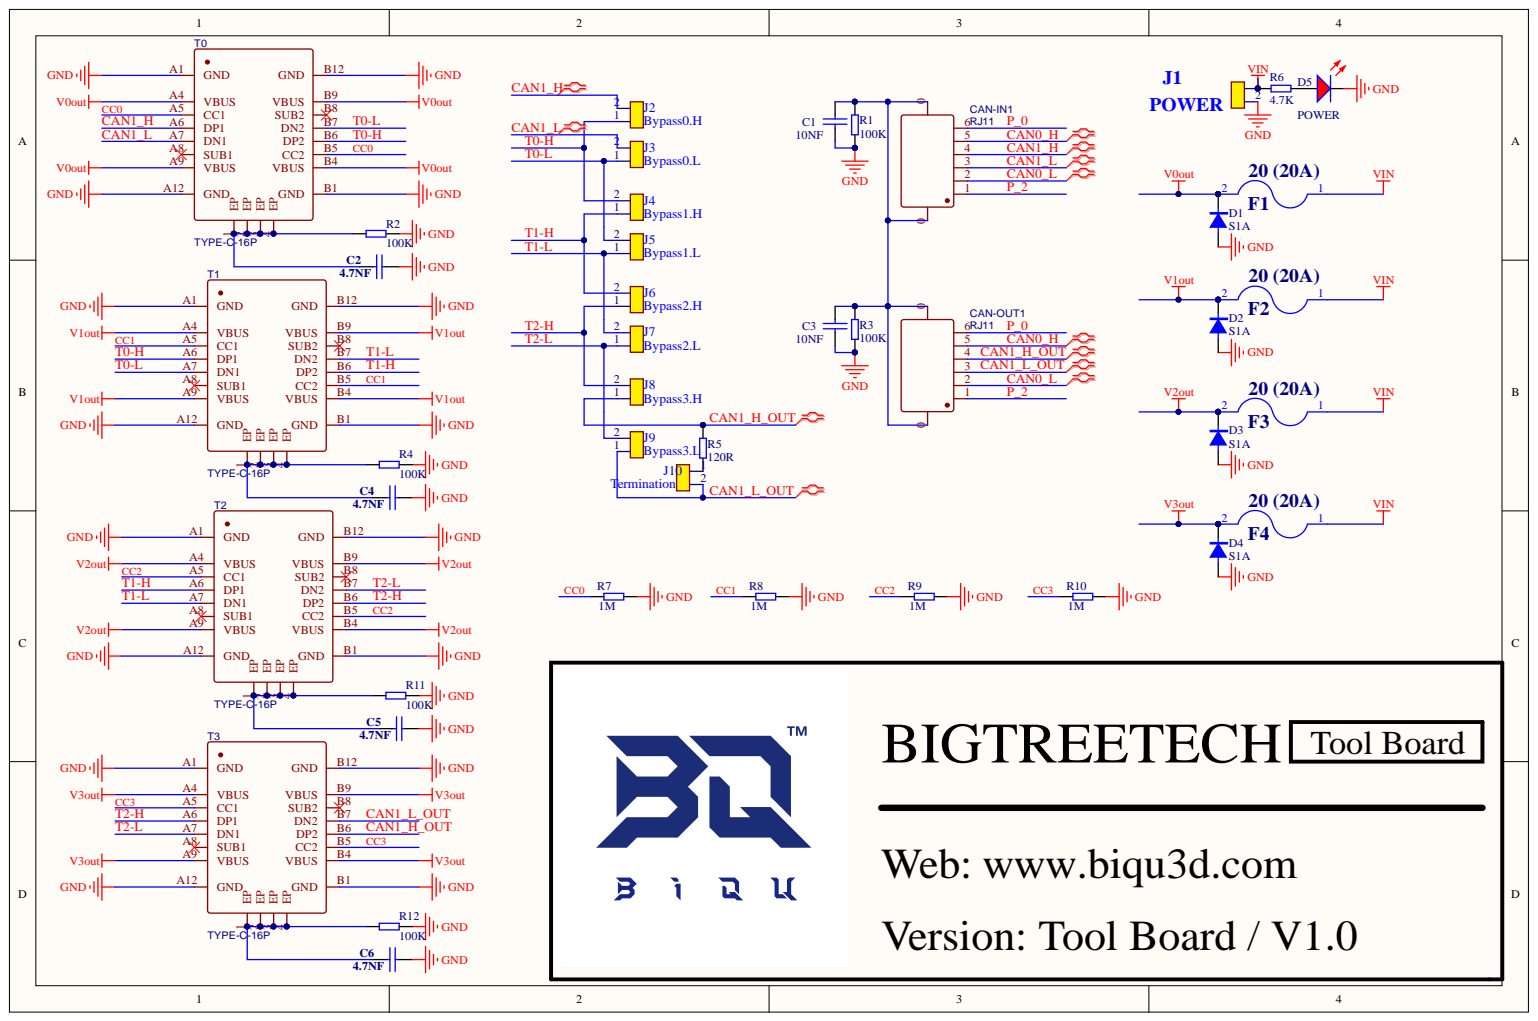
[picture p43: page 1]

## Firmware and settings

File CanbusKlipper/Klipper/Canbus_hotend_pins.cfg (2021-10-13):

# The "hotendboard" micro-controller will be used to control the components on the nozzle.


[mcu hotendboard]
canbus_uuid: 0e0d81e4210c

[adxl345]
cs_pin: hotendboard: PB12
spi_software_sclk_pin: hotendboard: PB13
spi_software_mosi_pin: hotendboard: PB15
spi_software_miso_pin: hotendboard: PB14
axes_map: y,z,-x
#   The accelerometer axis for each of the printer's x, y, and z axes.
#   This may be useful if the accelerometer is mounted in an
#   orientation that does not match the printer orientation. For
#   example, one could set this to "y,x,z" to swap the x and y axes.
#   It is also possible to negate an axis if the accelerometer
#   direction is reversed (eg, "x,z,-y"). The default is "x,y,z".
#rate: 3200
#   rates: 3200, 1600, 800, 400, 200, 100, 50, and 25

[resonance_tester]
accel_chip: adxl345
probe_points:
    100,100,20  # an example

[extruder]
step_pin: hotendboard: PA6
dir_pin: !hotendboard: PA7
enable_pin: !hotendboard: PA5
microsteps: 16
rotation_distance: 3.45
nozzle_diameter: 0.600
filament_diameter: 1.750
heater_pin: hotendboard: PA2
sensor_type: EPCOS 100K B57560G104F
sensor_pin: hotendboard: PA1
control: pid
pid_Kp: 21.527
pid_Ki: 1.063
pid_Kd: 108.982
min_temp: 0
max_temp: 250

[tmc2209 extruder]
uart_pin: hotendboard: PB0
run_current: 0.650
hold_current: 0.500
stealthchop_threshold: 999999


[heater_fan nozzle_cooling_fan]
pin: hotendboard: PA3


[heater_fan nozzle_cooling_fan1]
pin: hotendboard: PA4

[neopixel hotend_rgb]
pin: hotendboard:PA8
chain_count: 2
color_order: GRB
initial_RED: 0.5
initial_GREEN: 0.5
initial_BLUE: 0.5

[bltouch]
sensor_pin: ^hotendboard:PB2
control_pin: hotendboard:PB1
x_offset: -35
y_offset: -1
z_offset: 0.70

[bed_mesh]
speed: 120
horizontal_move_z: 5
mesh_min: 10,10
mesh_max: 190, 185
probe_count: 5,5

[safe_z_home]
home_xy_position: 120,100 # Change coordinates to the center of your print bed
speed: 50
z_hop: 10                 # Move up 10mm
z_hop_speed: 5

#[filament_switch_sensor hotend_sensor]
#pause_on_runout: True
#runout_gcode:
#   A list of G-Code commands to execute after a filament runout is
#   detected. See docs/Command_Templates.md for G-Code format. If
#   pause_on_runout is set to True this G-Code will run after the
#   PAUSE is complete. The default is not to run any G-Code commands.
#insert_gcode:
#   A list of G-Code commands to execute after a filament insert is
#   detected. See docs/Command_Templates.md for G-Code format. The
#   default is not to run any G-Code commands, which disables insert
#   detection.
#event_delay: 3.0
#   The minimum amount of time in seconds to delay between events.
#   Events triggered during this time period will be silently
#   ignored. The default is 3 seconds.
#pause_delay: 0.5
#   The amount of time to delay, in seconds, between the pause command
#   dispatch and execution of the runout_gcode. It may be useful to
#   increase this delay if OctoPrint exhibits strange pause behavior.
#   Default is 0.5 seconds.
#switch_pin: hotendboard:PA10

#[filament_motion_sensor encoder_sensor]
#detection_length: 3.5
#   The minimum length of filament pulled through the sensor to trigger
#   a state change on the switch_pin
#   Default is 7 mm.
#extruder: extruder
#   The name of the extruder section this sensor is associated with.
#   This parameter must be provided.
#switch_pin: ^hotendboard:PA9
#pause_on_runout: True
#runout_gcode:
#insert_gcode:
#event_delay:
#pause_delay:
#   See the "filament_switch_sensor" section for a description of the
#   above parameters.

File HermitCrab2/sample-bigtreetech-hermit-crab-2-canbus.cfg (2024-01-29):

# This file contains common pin mappings for the BIGTREETECH HermitCrab2
# Canbus board. To use this config, the firmware should be compiled for the
# RP2040 with "USB" or "CAN bus (on gpio4/gpio5)".

# See docs/Config_Reference.md for a description of parameters.

[mcu HermitCrab2]
serial: /dev/serial/by-id/usb-Klipper_Klipper_firmware_12345-if00
#canbus_uuid: 0e0d81e4210c
 
[temperature_sensor HermitCrab2_NTC]
sensor_type: Generic 3950
sensor_pin: HermitCrab2:gpio28

[lis2dw]
cs_pin: HermitCrab2:gpio1
spi_bus: spi0a
axes_map: y,z,-x

[extruder]
step_pin: HermitCrab2:gpio18
dir_pin: !HermitCrab2:gpio17
enable_pin: !HermitCrab2:gpio21
microsteps: 16
rotation_distance: 33.500
nozzle_diameter: 0.400
filament_diameter: 1.750
heater_pin: HermitCrab2:gpio22
sensor_type: EPCOS 100K B57560G104F
sensor_pin: HermitCrab2:gpio27
control: pid
pid_Kp: 21.527
pid_Ki: 1.063
pid_Kd: 108.982
min_temp: 0
max_temp: 250

# sensor_type:MAX31865
# sensor_pin: HermitCrab2:gpio9
# spi_bus: spi1a
# rtd_nominal_r: 100
# rtd_reference_r: 430
# rtd_num_of_wires: 2

[tmc2209 extruder]
uart_pin: HermitCrab2:gpio19
run_current: 0.650
stealthchop_threshold: 999999

[fan]
pin: HermitCrab2:gpio14

[heater_fan hotend_fan]
pin: HermitCrab2:gpio15
heater: extruder
heater_temp: 50.0

[fan_generic 4W_FAN]
pin: HermitCrab2:gpio13
tachometer_pin: HermitCrab2:gpio12

[neopixel hotend_rgb]
pin: HC2:gpio26

[bltouch]
sensor_pin: ^HermitCrab2:gpio24
control_pin: HermitCrab2:gpio23

#i2c_mcu: HermitCrab2 
#i2c_bus: i2c1b
##i2c_software_scl_pin: HermitCrab2:gpio7
##i2c_software_sda_pin: HermitCrab2:gpio6

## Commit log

2021-10-13 Canbus info
    [Canbus_hotend_pins.cfg]
2021-10-23 add STL
    [BIQU HERMIT CRAB TOOL PLATE.stl, HERMIT CRAB.stl, bracket.STL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]
2021-11-04 update firmware by raspberry pi dfu
    [HermitCrab_Canbus_pins.cfg]
2021-11-25 update cfg
    [HermitCrab_Canbus_pins.cfg]
2022-07-10 Updated direction about changed default `USB device ID`
2022-12-28 add cable clamp
    [hermit crab standard cable cover.STL]
2024-01-29 add hermit crab 2
    [BIQU HERMIT CRAB TOOL PLATE.stl, HERMIT CRAB.stl, HermitCrab_Canbus_pins.cfg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]
